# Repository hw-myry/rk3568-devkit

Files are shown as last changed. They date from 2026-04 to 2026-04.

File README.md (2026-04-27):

# rk3568-devkit

## Overview

**SoC**: RK3568  
**RAM**: LPDDR4  
**Storage**: eMMC  

**Interfaces**:  
USB OTG / USB2.0 / USB3.0 / PCIe 2.0  
MIPI DSI / MIPI CSI / HDMI  

**Ethernet**:  
RTL8211F-CG (Gigabit)

**Power**:  
RK809-5 PMIC  
CH224K (12V PD trigger)

**Debug**:  
UART  

**Audio**:  
MIC / SPK / Headphone

<p align="center">
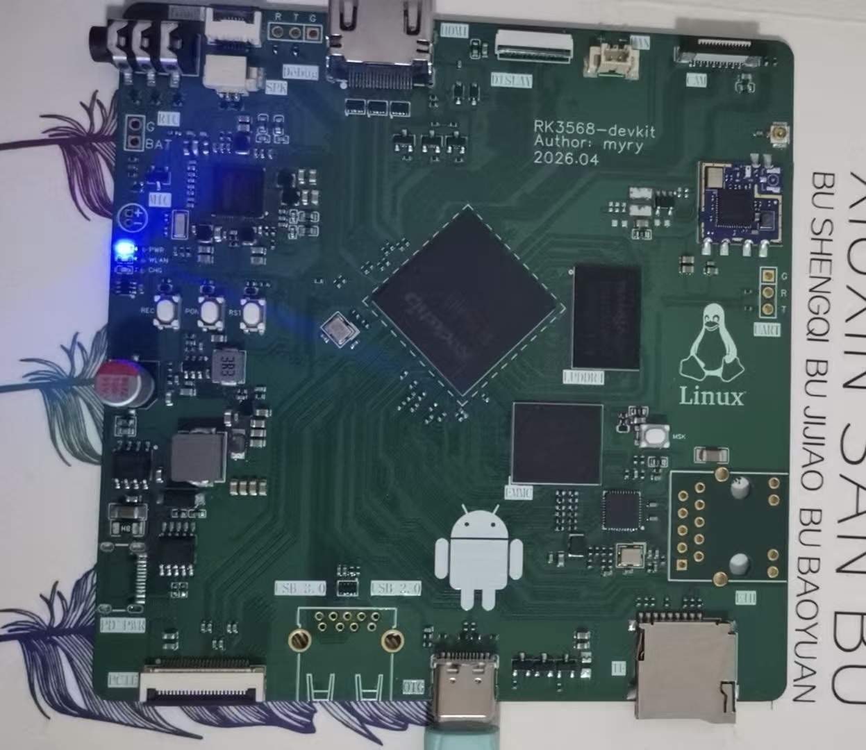
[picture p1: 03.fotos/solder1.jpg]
  
</p>

<p align="center">
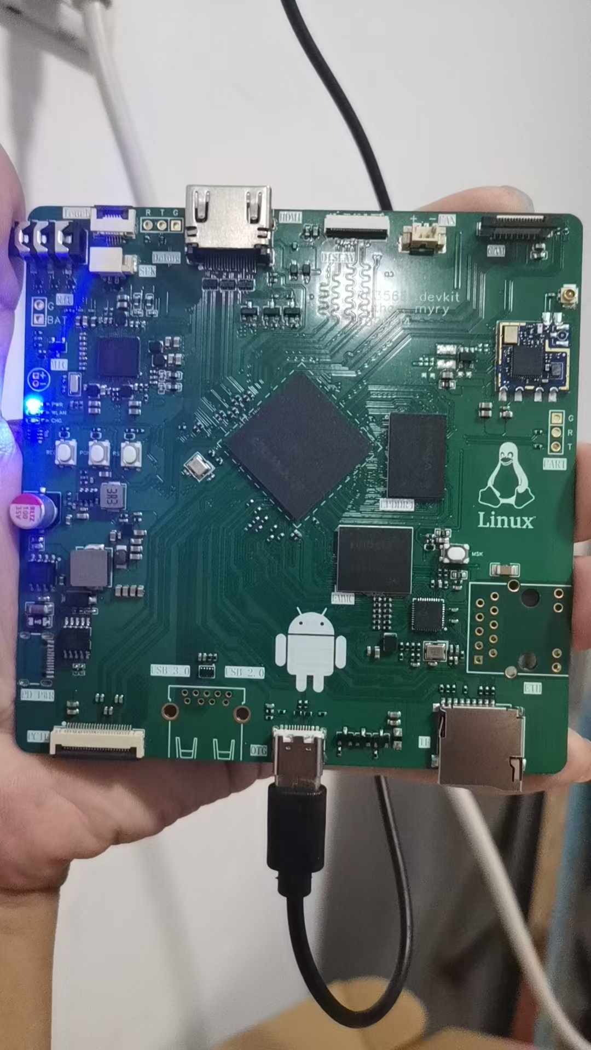
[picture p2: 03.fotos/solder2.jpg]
  
</p>

<p align="center">
  
</p>

<p align="center">
  
</p>

<p align="center">
  
</p>

<p align="center">
  
</p>

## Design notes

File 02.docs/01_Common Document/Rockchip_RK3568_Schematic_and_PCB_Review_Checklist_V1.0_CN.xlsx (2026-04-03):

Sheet: 封面页
RK3568原理图及PCB评审注意事项
Revision: | V1.0
Date: | 2021-04-16
Status: | Draft
Rockchip Confidential

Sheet: 声明
保密提示： 本文档及其附件可能含有机密信息，来自瑞芯微电子股份有限公司，仅发送给指定接收者。若非该特定接收人，请勿复制、 使用或披露本文档的任何内容。若误收本文档，请从系统中永久性删除本文档，并以回复邮件或其他方式即刻告知发件人。瑞芯微电子股份有限公司拥有本文档信息的著作权及解释权，禁止任何未经授权许可的侵权行为。 IMPORTANT NOTICE: This document is from Rockchip Electronics Co., Ltd. .The contents of this document and any attachments may contain information that is privileged, confidential and/or exempt from disclosure under applicable law and relevant NDA. If you are not the intended recipient, you are hereby notified that any disclosure, copying, distribution, or use of the information is STRICTLY PROHIBITED. Please immediately contact the sender as soon as possible and destroy the material in its entirety in any format. Thank you.

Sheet: 历史版本
Revision History
Revision | Description | Editor | Revision Date
V1.0 | First edition | Zhangdz | 2021.04.16

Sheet: Clock&Reset&PMU Circuit
类型 |  | 项目 | 要求 | 风险点及影响 | 是否验证? | 审核人 | 备注
平台共性 | 原理图 | 晶体负载电容请根据实际使用的晶体的CL电容值选择，并控制常温下的频率容限在20ppm以内，负载电容材质建议采用COG或NPO | 必须 | 设计要求
 |  | XOUT24M网络串接电阻（22ohm）必须保留，用于限流，防止过驱 | 必须 | 设计要求
 |  | XOUT24M和XIN24M网络之间的1M电阻不能随意修改 | 必须 | 设计要求
 |  | 建议采用贴片4Pin晶体，其中2个GND管脚与PCB板的地充分连接，加强时钟抗ESD干扰能力 | 必须 | 设计要求
 |  | TVSS管脚必须直接接地 | 必须 | 设计要求
 |  | 芯片nPOR管脚（RESETn网络）为输入管脚，必须由外部控制，默认由RK809-5控制，如果采用其它方案外部必须增加复位IC | 必须 | 设计要求
 |  | TSADC_SHUT包含了过温复位输出以及看门狗复位输出，由于TSADC_SHUT会连接到Resetn网络上，如果采用复位IC，必须使用OD输出，有效信号为低电平，复位时间不小于10mS即可 | 必须 | 设计要求
 |  | 芯片nPOR管脚（RESETn网络）需放置100nF电容，加强抗ESD干扰能力 | 必须 | 设计要求
 |  | PMIC_SLEEP和TSADC_SHUT是特定功能信号，不得随意更改。 | 必须 | 设计要求
 |  | FLASH_VOL_SEL管脚必须根据实际VCCIO2供电电压选择正确的高低电平（上拉或下拉），决定VCCIO2电源域供电电压和驱动电压是否匹配。 | 必须 | 设计要求
 |  | REFCLK_OUT网络建议串接22 ohm电阻，并靠近RK3568放置，提高信号质量。 | 必须 | 设计要求
 |  | 如果深度睡眠功耗要求比较极致，睡眠时钟需要外部提供，从Pin AD23管脚（CLK32K_IN）输入32.768KHz时钟。 | 可选项 | 影响二级待机功耗
 |  | 要求PMUPLL_AVDD_0V9，PMUPLL_AVDD_1V8，SYSPLL_AVDD_0V9，SYSPLL_AVDD_1V8，PMUIO1，PMUIO2，PMU_VDD_LOGIC_0V9电源的去耦电容不能删除，要求复制参考图设计 | 必须 | 设计要求
 | PCB | 晶体电路布局需要优先考虑，布局时应与芯片在同一层并尽量靠近放置以避免打过孔，晶体走线尽可能的短，远离干扰源，尽量远离板边缘， | 必须 | 设计要求
 |  | 晶体以及时钟信号需要全程包地处理，包地线每隔200mil至少添加一个GND过孔，并且必须保证邻层的地参考面完整。 | 必须 | 设计要求
 |  | 晶体电路布局时如果与芯片不同层放置，晶体走线及必须全程包地处理，避免被干扰。 | 必须 | 设计要求
 |  | PMUPLL_AVDD_0V9，PMUPLL_AVDD_1V8，SYSPLL_AVDD_0V9，SYSPLL_AVDD_1V8，PMUIO1，PMUIO2，PMU_VDD_LOGIC_0V9电源的去耦电容，必须放在芯片管脚背面，走线时，尽量形成先经过电容焊盘再到芯片管脚。 | 必须 | 设计要求
 |  | 在布局时，RESETn复位信号远离板边缘和金属接插件，以防止因ESD引起的异常而导致复位模块死机。 | 必须 | 设计要求
 |  | RESETn的滤波电容应尽量靠近芯片管脚布局，信号需先经过电容，再进入芯片，注意滤波电容的地焊盘必须有一个0402地过孔，空间允许建议打两个以上，更良好的接地。 | 必须 | 设计要求
 |  | RESETn信号应远离DCDC、RF等强干扰信号，以防止受到干扰。如果走线较长，建议包地处理，并且包地线每隔400mil至少添加一个GND过孔。 | 必须 | 设计要求
 |  | REFCLK_OUT必须全程包地处理，包地的走线间隔300mil以内必须有地过孔 | 必须 | 设计要求
 |  | RESETn按键的TVS保护二级管应尽量靠近按键放置，信号拓扑为：按键--->TVS--->100 ohm--->电容（靠近CPU&PMIC）--->CPU&PMIC；出现ESD现象时，ESD电流必须先经过TVS器件衰减。 | 必须 | 设计要求
扩展需求 | 原理图
 | PCB

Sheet: Debug UART&JTAG
类型 |  | 项目 | 要求 | 风险点及影响 | 是否验证? | 审核人 | 备注
平台共性 | 原理图 | UART2_RX_M0/UART2_TX_M0串接的100 ohm电阻不得删减，建议增加TVS管，加强抗静电浪涌能力，防止开发过程损坏芯片管脚。 | 必须 | 设计要求
 |  | 能预留2.54 插针建议尽量预留，如果无条件，建议使用0.7mm以上测试点，方便焊接。 | 必须 | 设计要求
 |  | RK3568的A55 Core JTAG Debug 只支持SWD模式，只需要预留ARMJTAG_TCK/ARMJTAG_TMS，和SDMMC0_D2/SDMMC0_D3复用，默认由SDMMC0_DET管脚（Pin Y22）做硬件切换，要进入JTAG模式，必须保证SDMMC0_DET管脚处于高电平，否则无法进入JTAG调试模式 | 必须 | 设计要求
 | PCB | TVS保护二级管应尽量靠近座子放置，信号拓扑为：接口--->TVS--->CPU；出现ESD现象时，ESD电流必须先经过TVS器件衰减；TVS器件走线上不要有残桩(Stub) | 必须 | 设计要求
 |  | TVS的地管脚建议尽量增加地过孔，至少保证2个0.4*0.2mm的过孔，加强静电泄放能力 | 必须 | 设计要求
扩展需求 | 原理图
 | PCB

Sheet: PMIC&Power
类型 |  | 项目 | 要求 | 风险点及影响 | 是否验证? | 审核人 | 备注
平台共性 | 原理图 | 默认电源方案采用RK809-5，即参考设计所提供的参考电路，如果需要更换，LDO/BUCK的带载能力、瞬态响应以及功率耗散要满足设计要求。如果不知道每一路电源的功耗数据，可向Rockchip申请EVB的电源测试数据做参考。 对BUCK的主要要求如下： 1）输出电压精度要求在±1.5% 2）BUCK瞬态响应要求：Iload=BUCK Max电流*10%-BUCK Max电流*80% 跳变，斜率1A/us，纹波要求±3%以内。 3）带载能力建议大于实际场景的最大峰值电流的150% 如果对整机功耗敏感的，还需要考虑一下效率问题。 | 必须 | 设计要求
 |  | RK3568芯片的每路电源管脚的去耦电容不得删减，要求参照参考设计。 | 必须 | 设计要求
 |  | 针对RK809-5电源方案的上下电时序：不能更改，已固化。 针对分立电源方案 上电时序：理论上遵循低压先上、高压后上，待最后一个电压上电稳定后，RESETn至少保证10mS才能释放，各模块上电时序要求请见《Rockchip_RK3568_Hardware_Design_Guide》 下电时序：VCC3V3_PMUIO电压降低于2.93V时 ，RESETn必须先拉低动作，其它电源随着下电。 | 可选项 | 设计要求
 |  | 如果有需要钮扣电池保存实时时钟，建议使用外部RTC IC（RK809-5的RTC电流大概35~50uA）。 | 可选项 | 设计要求
 |  | 使用外部的RTC IC当实时时钟，如果需要定时闹钟开机功能，请联系Rockchip FAE提供参考电路。 RK809-5自带的RTC支持定时闹钟开机功能。 使用外部的RTC IC必须确认一下其IO的电平和RTC芯片供电电源电压是否匹配 | 可选项 | 设计要求
 |  | RK809-5的32.768KHz晶体负载电容请根据实际使用的晶体的CL电容值选择，建议选择不低于18pF，负载电容过低有可能会造成起振不稳定，推荐值为22pF | 必须 | 设计要求
 |  | 适配器需要根据产品规格进行选型，比如有多个SATA或多个PCIe插槽需求，适配器输出的带载能力必须匹配上，RK3568以及最小系统这边需要按6-10W空间预留 | 必须 | 设计要求
 |  | 12V适配器方案： VCC5V0_SYS要求选择≥3A供电能力的BUCK。 VCC3V3_SYS要求选择≥3A供电能力的BUCK。 VCC5V0_USB要求选择≥3A供电能力的BUCK，如果有更多的USB接口或SATA接口的需求，供电能力必须匹配上。 | 必须 | 设计要求
 |  | DC输入端建议放置RC电路，可吸收DC插入瞬间的峰值电压，注意电阻的功率和电容的耐压。 | 必须 | 设计要求
 |  | DC输入端建议放置100uF以上容量的电容，改善电源纹波。
 |  | VCC5V0_SYS,VCC3V3_SYS,VCC5V0_USB建议各放置100uF以上容量的电容，获取最好的电源纹波。 | 必须 | 设计要求
 |  | 如果有需求快速上下电测试的产品，要注意电解电容的放电时间，如果存在下电不彻底又重新上电了，可能会引起系统工作异常，这种情况就需要考虑对其加放电电路处理，请联系Rockchip提供参考方案电路。 | 必须 | 设计要求
 |  | PMIC RK809-5电源时序以及电源分配是固定的，不能随意改动各路电源分配好的LDO和DC-DC。 | 必须 | 设计要求
 |  | PMIC RK809-5的DC-DC电感参考值为：感量0.47uH，饱和电流3.5A以上，DCR小于50毫欧。 | 必须 | 设计要求
 |  | PMIC RK809-5的DC-DC、LDO的输入输出电容容量需要参照参考设计，不能随意修改。 | 必须 | 设计要求
 |  | PMIC RK809-5的BUCK3输出电压值是由外围电阻决定的，必须根据项目所用的DDR类型匹配电压值，参考电压为0.8V，选择分压电阻RH=(VBUCK3-0.8)*RL/0.8，RH和RL分别为分压上拉电阻和下拉电阻，阻值选择建议在10KΩ 到1MΩ 之间，精度为1%，建议参照参考设计提供的参数。 | 必须 | 设计要求
 |  | USB_AVDD_0V9，USB_AVDD_1V8，MIPI_AVDD_0V9，MIPI_AVDD_1V8这几路电源必须串磁珠进行隔离，磁珠规格为120R-100MHz | 必须 | 设计要求
 |  | PMIC RK809-5外围器件必须完整复制参考设计，不得随意删减。 | 必须 | 设计要求
 |  | PMIC RK809-5的Pin 67（RESETB）也需要有100nF电容，加强抗ESD干扰能力，不能随意删掉。 | 必须 | 设计要求
 |  | PMIC RK809-5的SDA\SCL\INT \CLK32K\RESETB 这几个GPIO 是开漏输出的，允许输入的最高电压是VCC_RTC的电压，外部需要额外增加上拉电阻或使用RK3568 IO内部的上拉电阻。 SCL\SDA\SLEEP\PWRON\RESETB 做为输入VL\VH 是固定的0.4V\1.26V | 必须 | 设计要求
 |  | PMIC RK809-5的VCC_RTC（Pin45）：是RK809 芯片内部数字逻辑、部份模拟控制及RTC 时钟供电引脚 ，该脚设计时要求供电电压必须是RK809 所有供电脚中的最高电压（或是大于Vmax-0.3V），所以VCC_RTC 必须最先上电，或和其它电源一起上电，不允许出现VCC_RTC没电而其它电源先供电的情况。 建议和RK809-5的VCC9（Pin54）接同一个电源 | 必须 | 设计要求
 |  | RK809-5 VDC(Pin61）输入电压值推荐值为1.2V左右，不建议随意修改 | 必须 | 设计要求
 |  | 如果Gas Gauge不使用，建议Pin56（BATDIV）,Pin62（SNSP）,Pin63（SNSN）接地处理 | 必须 | 设计要求
 |  | 如果项目不使用RK809-5 CODEC功能，那么RK809-5的 Pin14(LRCLK),Pin15(BCLK),Pin16(MCLK),Pin17(SDI),Pin19(PDMCLK),Pin40(HP_SNS) 需要接地VSS处理， Pin18(SDO/PDMDATA),Pin36(CPn),Pin37(CPp),Pin38(VCC_CPVDD),Pin35(VCC_CPVSS),Pin39(HPL_OUT),Pin41(HPR_OUT),Pin34(SPK_OUTn),Pin32(SPK_OUTp),Pin43(MIC1p),Pin42(MIC1n)悬空处理即可 Pin33(VCC_SPK_HP),Pin48(VCC_1P8D),Pin44(VCC_1P8A)的电路必须保留。 | 必须 | 设计要求
 |  | VDD_LOGIC,VDD_GPU,VDD_NPU,VDD_CPU这几路电源DC-DC采用远端引入反馈补偿设计，弥补线路的电压损耗及提高电源动态调整及时性，由于实际生产或使用过程中若出现远端的反馈节点开路的情况，所以要求在DC-DC侧增加100 ohm电阻，这个电阻可以使输出电压依然稳定在设定值，避免因反馈点开路导致DC-DC输出电压失控导致主控过压损坏，另外反馈补偿线与电源线存在一个环路，某些设计可能会感应到噪声影响DC-DC，这个电阻可以在一定程度上减小这个影响，为了提升瞬态响应，在100 ohm电阻上面再并了一个100nF电容。 100ohm电阻和100nF电容不能随意删减。 | 必须 | 设计要求
 |  | VDD_CPU采用动态电压频率调整，要求参照参考图设计，通过I2C进行调压，如需更换其它型号，要求选择≥4A供电能力的BUCK BUCK其它要求如下： 1）输出电压精度要求在±1.5% 2）BUCK瞬态响应要求：Iload=BUCK Max电流*10%-BUCK Max电流*80% 跳变，斜率1A/us，纹波要求±5%以内。 | 必须 | 设计要求
 |  | 请勿删除参考图中电源管脚串接的电阻或磁珠，因为芯片需要RC或LC滤波设计 | 必须 | 设计要求
 | PCB | 整体布局时从电源质量角度上看RK809-5尽量靠近RK3568（考虑散热设计时，需要适当放置，不要太靠近也不能离的太远，建议间隔20mm-50mm之间，尽量不放置在板边，对散热不利），摆放方向时，需要使RK809-5的BUCK输出到RK3568的走线（铺铜）是顺的，不要存在交叉。 | 必须 | 设计要求
 |  | RK809-5的BUCK1/BUCK2 PCB设计要求： 输入电容必须离芯片尽可能近，输入电容与VCC1/2 和GND 的连接环路尽可能小。应当保证SW1/2 的走线尽可能短，防止对其他模块造成干扰；VFB1/2 走线应当尽量避免离SW1/2 太近。 对于需要打过孔的地方，VCC1/2 至少需要4个0.5*0.3mm 的过孔，VBUCK1/2 至少需要5 个0.5*0.3mm的过孔。 特别注意输入输出电容的GND 端要有和正端一样多数量的过孔，才能起到比较好的虑波效果。 | 必须 | 设计要求
 |  | RK809-5的BUCK3 PCB设计要求： 输入电容必须离芯片尽可能近，输入电容与VCC3 和GND 的连接环路尽可能小。应当保证SW3 的走线尽可能短，防止对其他模块造成干扰；VFB3 走线应当尽量避免离SW3 太近。 对于需要打过孔的地方，VCC3至少需要3 个0.5*0.3mm的过孔，VBUCK3 至少需要5 个0.5*0.3mm的过孔。 特别注意输入输出电容的GND 端要有和正端一样多数量的过孔，才能起到比较好的虑波效果。 | 必须 | 设计要求
 |  | RK809-5的BUCK4 PCB设计要求： 输入电容必须离芯片尽可能近，输入电容与VCC4 和GND 的连接环路尽可能小。应当保证SW4 的走线尽可能短，防止对其他模块造成干扰；VFB4 走线应当尽量避免离SW4太近。 对于需要打过孔的地方，VCC4至少需要3 个0.5*0.3mm的过孔，VBUCK4 至少需要5 个0.5*0.3mm的过孔。 特别注意输入输出电容的GND 端要有和正端一样多数量的过孔，才能起到比较好的虑波效果。 | 必须 | 设计要求
 |  | RK809-5的BUCK5 PCB设计要求： 输入电容必须离芯片尽可能近，输入电容与VCC9 和GND 的连接环路尽可能小。应当保证SW5 的走线尽可能短，防止对其他模块造成干扰；VFB5 走线应当尽量避免离SW5太近。 对于需要打过孔的地方，VCC9至少需要3 个0.5*0.3mm的过孔，VBUCK5 至少需要5 个0.5*0.3mm的过孔。 特别注意输入输出电容的GND 端要有和正端一样多数量的过孔，才能起到比较好的虑波效果。 | 必须 | 设计要求
 |  | RK809-5的LDO PCB设计要求： 输入电容必须离芯片尽可能近，输入电容与VCC5/6/7/8和GND 的连接环路尽可能小。 输出电容必须离芯片尽可能近，输出电容与LDO1/2/3/4/5/6/7/8/9和GND 的连接环路尽可能小。 | 必须 | 设计要求
 |  | RK809-5的32.768KHz晶体的XIN/XOUT信号走线越短越好且全程做包地处理，保证有完整的参考平面，晶体电路下不能有高速信号穿过。 | 必须 | 设计要求
 |  | RK809-5的VREF电容必须靠近管脚放置，远离其它干扰源，电容的地焊盘必须良好接地，即VREF电容地焊盘和RK809-5 EPAD之间路径必须保证最短，不得被其他信号分割。 | 必须 | 设计要求
 |  | RK809-5的Pin 67（RESETB）的100nF电容必须靠近RK809-5管脚
 |  | 建议RK809-5的管脚禁铺铜，所有管脚通过走线方式和外面连接，走线线宽不得超过管脚宽度，防止制板后，焊盘变大后贴片容易连锡 | 必须 | 设计要求
 |  | RK809-5的EPAD接地焊盘要有足够的过孔，建议保证5*5个0.5*0.3mm或是6*6个0.4*0.2mm的过孔以上，降低接地阻抗，以及加强热量传导。 | 必须 | 设计要求
 |  | VDD_CPU（TCS4525）BUCK的PCB设计要求： 整体布局时，尽量靠RK3568。 输入电容必须离芯片尽可能近，输入电容与VIN和GND 的连接环路尽可能小。应当保证SW 的走线尽可能短，防止对其他模块造成干扰；VOUT 走线应当尽量避免离SW 太近。输出电容和GND的连接环路尽可能有小。 对于需要打过孔的地方，VIN至少需要5 个0.5*0.3mm的过孔，Vbuck输出至少需要12 个0.5*0.3mm的过孔。 特别注意输入输出电容的GND 端要有和正端一样多数量的过孔，才能起到比较好的虑波效果。 | 必须 | 设计要求
 |  | VDD_LOGIC,VDD_GPU,VDD_NPU,VDD_CPU的DC-DC 100ohm反馈电阻需要靠近输出电容放置，电阻一端连接到DC-DC输出电容，另一端连接到PMIC的FB反馈脚上，并同时连接到CPU同一电源网络的最远端负载处。反馈线宽度使用4mil，必须与电源铺铜伴随走线，以避免干扰；反馈线与其他信号间隔6mil以上，比如VDD_GPU的反馈线图片 | 必须 | 设计要求
 |  | VDD_LOGIC,VDD_GPU,VDD_NPU,VDD_CPU,VCC_DDR的铺铜宽度需满足芯片的电流需求，连接到芯片电源管脚的铺铜足够宽，路径不能被过孔分割太严重，必须计算有效线宽，确认连接到CPU每个电源PIN脚的路径都足够。 VDD_LOGIC：CPU区域的线宽不得小于60mil，外围区域宽度不小于200mil，尽量采用铺铜方式，降低走线带来压降 VDD_GPU：CPU区域的线宽不得小于50mil，外围区域宽度不小于200mil，尽量采用铺铜方式，降低走线带来压降 VDD_NPU：CPU区域的线宽不得小于50mil，外围区域宽度不小于200mil，尽量采用铺铜方式，降低走线带来压降 VDD_CPU：CPU区域的线宽不得小于120mil，外围区域宽度不小于200mil，尽量采用铺铜方式，降低走线带来压降 VCC_DDR：CPU区域的线宽不得小于120mil，外围区域宽度不小于200mil，尽量采用铺铜方式，铺铜覆盖DDR走线区域，降低走线带来压降 | 必须 | 设计要求
 |  | 芯片的各路电源在外围换层时，要尽可能的多打电源过孔，降低换层过孔带来的压降；去耦电容的GND过孔要跟它的电源过孔数量保持一致，否则会大大降低电容作用。 VDD_LOGIC:8个以上0.5*0.3mm的过孔 VDD_GPU:5个以上0.5*0.3mm的过孔 VDD_NPU:5个以上0.5*0.3mm的过孔 VDD_CPU:12个以上0.5*0.3mm的过孔 VCC_DDR:8个以上0.5*0.3mm的过孔 芯片其它电源：1个以上0.5*0.3mm的过孔或2个以上0.4*0.2mm的过孔 芯片外围电源：根据实际电流放置。 | 必须 | 设计要求
 |  | RK3568芯片的相邻层必须是一个完整的GND平面，保证主参考地靠近CPU的Ball，用于保证电源完整性以及加强PCB的散热。 | 必须 | 设计要求
 |  | RK3568芯片的Power管脚，每个Ball需要对应一个过孔。 | 必须 | 设计要求
 |  | RK3568芯片的GND管脚，至少保证每1.5个ball需要对应一个过孔，尽量每个Ball对应一个过孔，提供更优的SI,PI条件，以及对散热也有帮助。 | 必须 | 设计要求
 |  | RK3568芯片下方相同网络的Power Ball和GND Ball在顶层走“井”字形，交叉连接，建议走线线宽10mil | 必须 | 设计要求
 |  | GND层设计：在Layout时，RK3568的各信号放置换层过孔时，要求打在Ball间隔的正中间，要有规律的放置，如图，GND层的铺铜情况，RK3568芯片中间的地有大面积的铜皮和外面地铜皮连接，一方面有利于电源，信号完整性，另外一方面有利于芯片散热。 | 必须 | 设计要求
 |  | RK3568的各路电源去耦电容务必放在对应的电源管脚背面，特别是VDD_LOGIC,VDD_GPU,VDD_NPU,VDD_CPU,VCC_DDR电源至少放一个10uF以上容量的电容在管脚背面，电容的GND pad靠近芯片中心的GND Ball放置。 | 必须 | 设计要求
 |  | 去耦电容的换层过孔要满足带载能力，不管是电源输入、电源输出还是接地，必须有足够多的过孔，才能保证低ESR（用于减低回路电感），保证电容的去耦效果。 Rockchip建议10uF容量以上去耦电容，一个焊盘提供两个以上0.4*0.2mm的过孔，10uF以下容量的电容，一个焊盘提供至少一个0.4*0.2mm的过孔，过孔要靠近电容焊盘。 | 必须 | 设计要求
 |  | 电源部分布局远离其它发热源，以控制局部发热量过高不利于散热的问题。
 |  | 电源部分布局时应远离板边及金属接插件，防止ESD干扰。 | 必须 | 设计要求
扩展需求 | 原理图 Schematic | 如果使用RK809-5的电量计，请联系Rockchip申请参考电路图。 | 可选项
 | PCB | PMIC的32.768K晶体，如果使用金属圆柱体封装，金属外壳应接地。 | 必须 | 保证时钟稳定
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

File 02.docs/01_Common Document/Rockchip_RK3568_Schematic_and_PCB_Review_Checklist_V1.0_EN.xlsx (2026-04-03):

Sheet: title page
RK3568 Schematic and PCB Review Checklist
Revision: | V1.0
Date: | 2022-01-25
Status: | Draft
Rockchip Confidential

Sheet: state
保密提示： 本文档及其附件可能含有机密信息，来自瑞芯微电子股份有限公司，仅发送给指定接收者。若非该特定接收人，请勿复制、 使用或披露本文档的任何内容。若误收本文档，请从系统中永久性删除本文档，并以回复邮件或其他方式即刻告知发件人。瑞芯微电子股份有限公司拥有本文档信息的著作权及解释权，禁止任何未经授权许可的侵权行为。 IMPORTANT NOTICE: This document is from Rockchip Electronics Co., Ltd. .The contents of this document and any attachments may contain information that is privileged, confidential and/or exempt from disclosure under applicable law and relevant NDA. If you are not the intended recipient, you are hereby notified that any disclosure, copying, distribution, or use of the information is STRICTLY PROHIBITED. Please immediately contact the sender as soon as possible and destroy the material in its entirety in any format. Thank you.

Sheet: revision history
Revision History
Revision | Description | Editor | Revision Date
V1.0 | First edition | Zhangdz | 2021.04.16

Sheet: Clock&Reset&PMU Circuit
Type |  | Item | Requirement | Risk & Influence | Is it verified? | Reviewer | Remark
Platform Commonality | Schematic | Please select the crystal load capacitor according to the CL capacitance value of the crystal actually used, and control the frequency tolerance at room temperature within 20ppm. The material of the load capacitor is recommended to use COG or NPO. | Mandatory | Design requirement
 |  | XOUT24M network series resistor (22ohm) must be reserved for current limiting and preventing overdrive | Mandatory | Design requirement
 |  | The 1M resistance between the XOUT24M and XIN24M networks cannot be modified at will | Mandatory | Design requirement
 |  | It is recommended to use SMD 4Pin crystal, of which 2 GND pins are fully connected to the ground of the PCB board to enhance the anti-ESD interference capability of the clock | Mandatory | Design requirement
 |  | TVSS pin pin must be directly grounded | Mandatory | Design requirement
 |  | The nPOR pin (RESETn network) of the chip is an input pin, which must be controlled externally. It is controlled by RK809-5 by default. If other solutions are used, an external reset IC must be added. | Mandatory | Design requirement
 |  | TSADC_SHUT includes over temperature reset output and watchdog reset output. Since TSADC_SHUT will be connected to the Resetn network, if a reset IC is used, OD output must be used, the valid signal is low level, and the reset time is not less than 10mS. | Mandatory | Design requirement
 |  | The chip nPOR pin (RESETn network) needs to place a 100nF capacitor to enhance the anti-ESD interference ability | Mandatory | Design requirement
 |  | PMIC_SLEEP and TSADC_SHUT are function specific signals and should not be changed arbitrarily. | Mandatory | Design requirement
 |  | The FLASH_VOL_SEL pin must select the correct high and low level (pull-up or pull-down) according to the actual VCCIO2 power supply voltage to determine whether the power supply voltage of the VCCIO2 power domain matches the driving voltage. | Mandatory | Design requirement
 |  | It is recommended to connect a 22 ohm resistor in series with the REFCLK_OUT network and place it close to the RK3568 to improve signal quality. | Mandatory | Design requirement
 |  | If the power consumption of deep sleep is extreme, the sleep clock needs to be provided externally, and the 32.768KHz clock is input from the Pin AD23 pin (CLK32K_IN). | Optional | Affects secondary standby power consumption
 |  | It is required that the decoupling capacitors of the PMUPLL_AVDD_0V9, PMUPLL_AVDD_1V8, SYSPLL_AVDD_0V9, SYSPLL_AVDD_1V8, PMUIO1, PMUIO2, PMU_VDD_LOGIC_0V9 power supplies cannot be deleted, and the reference diagram design is required to be copied | Mandatory | Design requirement
 | PCB | The crystal circuit layout needs to be prioritized. The layout should be placed on the same layer as the chip and placed as close as possible to avoid vias. The crystal traces should be as short as possible, away from interference sources, and as far away as possible from the edge of the board. | Mandatory | Design requirement
 |  | The crystal and clock signals need to be grounded in the whole process. At least one GND via is added every 200mil to the grounded wire, and the ground reference plane of the adjacent layer must be guaranteed to be complete. | Mandatory | Design requirement
 |  | If the crystal circuit layout is placed on a different layer from the chip, the crystal wiring and wiring must be handled in the whole process to avoid interference. | Mandatory | Design requirement
 |  | PMUPLL_AVDD_0V9, PMUPLL_AVDD_1V8, SYSPLL_AVDD_0V9, SYSPLL_AVDD_1V8, PMUIO1, PMUIO2, PMU_VDD_LOGIC_0V9 power supply decoupling capacitors must be placed on the back of the chip pins. When routing, try to form them first through the capacitor pads and then to the chip pins. | Mandatory | Design requirement
 |  | During layout, the RESETn reset signal is kept away from the board edge and metal connectors to prevent the reset module from crashing due to anomalies caused by ESD. | Mandatory | Design requirement
 |  | The filter capacitor of RESETn should be placed as close as possible to the chip pins. The signal needs to pass through the capacitor first, and then enter the chip. Note that the ground pad of the filter capacitor must have a 0402 ground via. It is recommended to use more than two if the space allows, for better grounding. | Mandatory | Design requirement
 |  | The RESETn signal should be kept away from strong interference signals such as DCDC and RF to prevent interference. If the trace is long, it is recommended to cover the ground, and add at least one GND via hole every 400mil. | Mandatory | Design requirement
 |  | REFCLK_OUT must be grounded in the whole process, and the grounded traces must have ground vias within 300mil | Mandatory | Design requirement
 |  | The TVS protection diode of the RESETn button should be placed as close as possible to the button. The signal topology is: button--->TVS--->100 ohm--->capacitor (close to CPU&PMIC)--->CPU&PMIC; when ESD occurs, The ESD current must first decay through the TVS device. | Mandatory | Design requirement
Extended Requirement | Schematic
 | PCB

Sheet: Debug UART&JTAG
Type |  | Item | Requirement | Risk & Influence | Is it verified? | Reviewer | Remark
Platform Commonality | Schematic | The 100 ohm resistor connected in series with UART2_RX_M0/UART2_TX_M0 must not be deleted. It is recommended to add a TVS tube to enhance the anti-static surge capability and prevent the chip pins from being damaged during the development process. | Mandatory | Design requirement
 |  | It is recommended to reserve 2.54 pins as much as possible. If there are no conditions, it is recommended to use a test point of 0.7mm or more, which is convenient for welding. | Mandatory | Design requirement
 |  | A55 Core JTAG Debug of RK3568 only supports SWD mode, only need to reserve ARMJTAG_TCK/ARMJTAG_TMS, multiplex with SDMMC0_D2/SDMMC0_D3, the default is SDMMC0_DET pin (Pin Y22) for hardware switching, to enter JTAG mode, it must be ensured that SDMMC0_DET pin is in High level, otherwise cannot enter JTAG debug mode | Mandatory | Design requirement
 | PCB | The TVS protection diode should be placed as close as possible to the socket, and the signal topology is: interface--->TVS--->CPU; when ESD occurs, the ESD current must be attenuated by the TVS device first; there should be no residue on the TVS device trace. Stub | Mandatory | Design requirement
 |  | It is recommended to increase the ground vias as much as possible for the ground pins of TVS, and at least ensure 2 vias of 0.4*0.2mm to enhance the electrostatic discharge capability. | Mandatory | Design requirement
Extended Requirement | Schematic
 | PCB
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

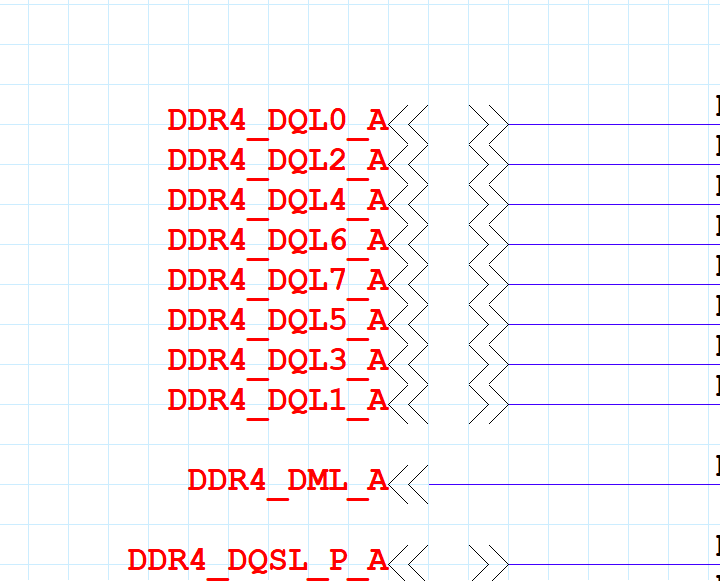
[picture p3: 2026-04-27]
02.docs/04_Product Line Branch(NVR)/03_Demo Reference Design/SCH/RK_NVR_DEMO_RK3568_DDR4P216SD4_V12_20201221.png

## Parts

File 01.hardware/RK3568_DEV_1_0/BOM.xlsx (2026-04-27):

No. | Quantity | Comment | Designator | Footprint | Value
1 | 1 | 0.1uF | C1 | C0201 | 0.1uF
2 | 14 | 22uF | C2,C3,C7,C8,C9,C13,C14,C15,C17,C18,C212,C214,C342,C343 | C0603 | 22uF
3 | 7 | 100nF | C4,C5,C138,C510,C538,C540,C543 | C0603 | 100nF
4 | 38 | 100nF | C6,C11,C16,C21,C23,C25,C27,C29,C30,C32,C33,C35,C36,C37,C38, C39,C40,C41,C42,C43,C44,C46,C48,C49,C52,C53,C56,C57,C58,C60, C63,C64,C66,C68,C69,C70,C71,C72 | C0201 | 100nF
5 | 8 | 4.7uF | C10,C12,C222,C223,C227,C228,C229,C244 | C0402 | 4.7uF
6 | 4 | 100nF | C19,C221,C225,C226 | C0201 | 100nF
7 | 2 | 22pF | C20,C22 | c0402-nsk | 22pF
8 | 9 | 1uF | C24,C26,C31,C34,C108,C132,C238,C541,C542 | c0402-nsk | 1uF
9 | 1 | 1uF | C28 | C0402 | 1uF
10 | 8 | 4.7uF | C45,C47,C50,C51,C185,C187,C190,C192 | c0402-nsk | 4.7uF
11 | 2 | 100pF | C54,C201 | c0402-nsk | 100pF
12 | 17 | 22uF | C55,C59,C62,C75,C84,C85,C98,C101,C103,C146,C166,C207,C215,C216,C217,C218,C339 | C0603_1 | 22uF
13 | 1 | 1uF | C61 | C0201 | 1uF
14 | 2 | 10uF | C65,C67 | C0603_1 | 10uF
15 | 26 | 1uF | C73,C74,C77,C78,C79,C80,C81,C86,C87,C88,C89,C90,C92,C93,C95,C96,C97,C105,C106,C107, C113,C114,C117,C118,C149,C197 | R0402_1 | 1uF
16 | 13 | 10uF | C76,C82,C83,C91,C94,C99,C102,C104,C139,C147,C148,C240,C341 | C0603_2 | 10uF
17 | 47 | 100nF | C100,C123,C126,C127,C128,C129,C140,C141,C142,C143,C144,C145,C150,C151,C152,C153,C154,C155,C156, C157,C158,C159,C160,C161,C162,C163,C164,C165,C169,C170,C171,C172,C173,C174,C175,C176,C177,C178, C179,C180,C181,C182,C183,C195,C196,C336,C337 | R0402_1 | 100nF
18 | 1 | 4.7uF | C109 | R0402_1 | 4.7uF
19 | 29 | 100nF | C110,C131,C135,C136,C137,C184,C186,C189,C191,C193,C194,C202,C208,C209,C210,C347,C352,C353,C354, C355,C356,C359,C360,C361,C363,C364,C498,C515,C528 | c0402-nsk | 100nF
20 | 4 | 100nF | C111,C115,C119,C122 | R0402_3 | 100nF
21 | 2 | 12pF | C112,C116 | R0402_2 | 12pF
22 | 2 | 680pF | C120,C121 | R0402_1 | 680pF
23 | 2 | 27pF | C124,C125 | R0402_1 | 27pF
24 | 2 | 22uF | C130,C134 | c0603-nsk | 22uF
25 | 1 | 100nF | C133 | R0603 | 100nF
26 | 2 | 10uF | C167,C168 | R0402_1 | 10uF
27 | 1 | 2.2uF | C188 | c0402-nsk | 2.2uF
28 | 1 | 220pF | C198 | R0402_1 | 220pF
29 | 1 | 1uF | C199 | C0402_1 | 1uF
30 | 1 | DNP | C200 | c0402-nsk | 1nF
31 | 3 | 10uF | C211,C224,C514 | C0603 | 10uF
32 | 1 | 10uF | C213 | R0603 | 10uF
33 | 2 | 1uF | C219,C220 | MYC0402 | 1uF
34 | 2 | 4.7uF | C234,C351 | C0603 | 4.7uF
35 | 1 | 100nF | C239 | R0603_1 | 100nF
36 | 1 | 22pF | C338 | R0402_1 | 22pF
37 | 1 | 1nF | C345 | C1206 | 1nF
38 | 1 | 10nF | C346 | c0402-nsk | 10nF
39 | 2 | 18pF | C348,C349 | c0402-nsk | 18pF
40 | 1 | 2.7PF | C530 | c0402-nsk | 2.7PF
41 | 1 | 10nF | C536 | C0603 | 10nF
42 | 1 | 100uF | C537 | CAP-SMD_BD6.3-L6.6-W6.6-RD | 100uF
43 | 1 | 10uF | C539 | C1206 | 10uF
44 | 1 | TF PUSH | CARD1 | TF-SMD_TF-PUSH
45 | 1 | PJ-313D | CN3 | AUDIO-SMD_PJ-313D-2
46 | 1 | BAT54C,215 | D1 | SOT-23-3_L2.9-W1.6-P1.90-LS2.8-BR
47 | 4 | ESD73034D | D2,D3,D29,D30 | DFN-10_L2.5-W1.0-P0.50-BL-2
48 | 2 | SS34 | D6,D32 | SMA_L4.3-W2.6-LS5.0-FD
49 | 2 | B5819WS-TP | D27,D28 | SOD-323_L1.8-W1.3-LS2.5-RD
50 | 1 | BSMD0805L-200 | F2 | F0805
51 | 1 | HC-FPC-03-09-31RLTAG | FPC1 | FPC-SMD_31P-P0.30_HC-FPC-03-09-31RLTAG
52 | 1 | FPC-05F-6PH20 | FPC2 | FPC-SMD_6P-P0.50_XUNPU_FPC-05F-6PH20
53 | 1 | AFC01-S24FCA-00 | FPC3 | FPC-SMD_24P-P0.50_AFC01-S24FCA-00
54 | 2 | HDR-M_2.54_1x3P | H1,H2 | HDR-TH_3P-P2.54-V-M
55 | 1 | HDR-M_2.54_1x2P | H5 | HDR-TH_2P-P2.54-V-M-1
56 | 1 | HDMI 19PIN 043 | HDMI1 | HDMI-SMD_HDMI-19PIN-043
57 | 5 | 470nH | L1,L2,L3,L4,L5 | IND-SMD_L2.0-W1.6_MHCHL201610A-1R0M-Q8A | 470nH
58 | 1 | BLM15AG121SN1D | L6 | L0402
59 | 6 | BLM18PG121SN1D | L7,L9,L11,L12,L23,L24 | L0603_1
60 | 2 | BLM18PG181SN1D | L8,L10 | L0603
61 | 1 | 240nH | L13 | IND-SMD_L2.5-W2.0_WPN252012H
62 | 1 | 15uH | L14 | IND-SMD_L7.3-W6.8 | 15uH
63 | 1 | 10uH | L16 | IND-SMD_L2.5-W2.0 | 10uH
64 | 1 | 3.3uH | L18 | IND-SMD_L4.4-W4.2 | 3.3uH
65 | 1 | HR911130C | L19 | RJ45-TH_HR911130C
66 | 1 | 2.2uH | L20 | IND-SMD_L2.5-W2.0_MHCHL2520 | 2.2uH
67 | 1 | GMI4015P-2C-42db | MIC1 | MIC-TH_BD4.0-P1.40-D0.4-L-FD
68 | 3 | LED_0402-R | PW,PW1,PW2 | LED_0402
69 | 4 | Key_SMD_4.2x3.2x2.5 | PWR,RST,RST1,RST2 | Key_SMD_4.2x3.2x2.5
70 | 1 | PUMH9,115 | Q1 | SOT-363_L2.0-W1.3-P0.65-LS2.1-BL
71 | 3 | AO3400A_N | Q2,Q3,Q4 | SOT-23-3_L2.9-W1.3-P1.90-LS2.4-BR
72 | 1 | CJ2301 S1 | Q5 | SOT-23-3_L3.0-W1.7-P0.95-LS2.9-BR
73 | 2 | MMBT5401 | Q6,Q7 | SOT-23-3_L2.9-W1.3-P1.90-LS2.4-BR
74 | 26 | 22 | R1,R13,R14,R15,R16,R17,R18,R20,R22,R27,R42,R64,R80,R81,R346,R347,R348,R349,R350,R351, R366,R367,R368,R369,R370,R371 | R0402 | 22
75 | 1 | 0Ω | R2 | r0402-nsk | 0Ω
76 | 1 | 1M | R3 | R0402 | 1M
77 | 6 | 0 | R5,R375,R376,R379,R380,R381 | R0402 | 0
78 | 8 | 100 | R6,R10,R40,R41,R47,R372,R377,R378 | R0402 | 100
79 | 1 | 120 | R7 | R0402 | 120
80 | 1 | 120Ω | R8 | r0402-nsk | 120Ω
81 | 10 | 2.2 | R9,R19,R21,R33,R34,R35,R36,R37,R325,R326 | R0402 | 2.2
82 | 1 | 200 | R12 | R0201 | 200
83 | 10 | 10K | R23,R67,R73,R74,R75,R171,R214,R216,R320,R336 | R0402 | 10K
84 | 8 | 4.7K | R24,R29,R352,R354,R356,R357,R358,R359 | R0402 | 4.7K
85 | 2 | DNP | R26,R28 | R0402 | 4.7K
86 | 1 | 1.62K | R32 | R0201 | 1.62K
87 | 5 | 0 | R38,R68,R323,R361,R362 | R0603 | 0
88 | 1 | 2.2k | R43 | R0402 | 2.2k
89 | 1 | 24kΩ | R44 | R0402 | 24kΩ
90 | 1 | 1kΩ | R45 | R0402 | 1kΩ
91 | 2 | 10kΩ | R46,R49 | R0402 | 10kΩ
92 | 2 | 51kΩ | R48,R66 | R0402 | 51kΩ
93 | 3 | 0402WGF1000TCE | R50,R51,R53 | R0402_1
94 | 3 | 0Ω | R52,R57,R61 | R0402_1 | 0Ω
95 | 2 | 47kΩ | R55,R166 | R0402_1 | 47kΩ
96 | 1 | 120kΩ | R56 | R0402_1 | 120kΩ
97 | 1 | 180kΩ | R59 | R0402_1 | 180kΩ
98 | 2 | 10kΩ | R60,R63 | R0402_1 | 10kΩ
99 | 1 | 56kΩ | R62 | R0402_1 | 56kΩ
100 | 1 | 100Ω | R65 | R0402 | 100Ω
101 | 5 | 2.2K | R69,R173,R174,R175,R176 | R0402 | 2.2K
102 | 1 | 0Ω | R70 | R0603_2 | 0Ω
103 | 2 | 240 | R71,R72 | r0402-nsk | 240
104 | 1 | 47K | R76 | R0402 | 47K
105 | 4 | 1K | R82,R83,R84,R219 | R0402 | 1K
106 | 1 | 3.24K | R85 | R0603 | 3.24K
107 | 1 | 30kΩ | R164 | R0402_1 | 30kΩ
108 | 1 | 33kΩ | R167 | R0402_1 | 33kΩ
109 | 1 | 150kΩ | R168 | R0402_2 | 150kΩ
110 | 2 | 2K | R169,R170 | R0402 | 2K
111 | 3 | 1.8K | R215,R217,R342 | R0402 | 1.8K
112 | 1 | 27K | R218 | R0402 | 27K
113 | 1 | 100K | R220 | R0402 | 100K
114 | 2 | 3.6R | R321,R322 | R0603 | 3.6R
115 | 1 | 100kΩ | R328 | R0402_1 | 100kΩ
116 | 1 | 4.7kΩ | R329 | R0402_1 | 4.7kΩ
117 | 1 | 20K | R337 | R0402 | 20K
118 | 2 | 510R | R343,R344 | R0402 | 510R
119 | 1 | 2.49K | R345 | R0402 | 2.49K
120 | 1 | 10K | R374 | R0603 | 10K
121 | 2 | 5.1K | R382,R383 | R0402 | 5.1K
122 | 1 | 6GHz | RF1 | IPEX-SMD_BWIPX-1-001E | 6GHz
123 | 1 | 24MHz | U1 | CRYSTAL-SMD_4P-L3.2-W2.5-BL | 24MHz
124 | 1 | TCS4525_WT | U2 | TCS4525
125 | 1 | EMMC04G-M627-A01 | U3 | fbga-153_l13.0-w11.5-p0.50_klmag1jetd-b041
126 | 1 | RK3568 | U4 | BGA-636_L19.0-W19.0-P0.65-BL
127 | 1 | RK809-5 | U5 | RK809-5
128 | 1 | LPDDR4 | U6 | LPDDR4_MrX
129 | 4 | ESD5451N | U8,U9,U10,U11 | X1-DFN1006-2_L1.0-W0.6-P0.65-BI
130 | 6 | ESD5311X | U12,U13,U73,U74,U77,U81 | DFN1006-2L-BI
131 | 13 | ESD5341N | U14,U18,U19,U52,U53,U54,U55,U56,U57,U80,U82,U83,U84 | DFN1006-2L-BI_1
132 | 1 | CH224K | U15 | ESSOP-10_L4.9-W3.9-P1.0-LS6.0-TL-EP
133 | 1 | BSMD1206-100-13.2V | U16 | F1206
134 | 2 | ZX-MX1.25-2PLT | U17,U20 | CONN-SMD_2P-P1.25-MX1.25-2P-LT
135 | 1 | SY8113BADC | U26 | TSOT-23-6_L2.9-W1.6-P0.95-LS2.8-BR
136 | 1 | TPS5430DDAR | U27 | ESOP-8_L4.9-W3.9-P1.27-LS6.0-TL-EP
137 | 1 | RTL8211F-CG | U50 | RTL8211F-CG
138 | 1 | X05C2015GZ | U58 | FPC-SMD_15P-P0.50_XKB_X05C2015GZ
139 | 1 | BL_M8800DU6_40L | U69 | BL_M8800DU6_40L
140 | 1 | SY6280AAC | U78 | SOT-23-5_L3.0-W1.7-P0.95-LS2.8-BL
141 | 1 | SY7201ABC | U79 | SOT-23-6_L2.9-W1.6-P0.95-LS2.8-BR
142 | 2 | USB_TYPE-C-16P | USB1,USB2 | USB_TYPE-C-16P
143 | 1 | USB-301WD-ARY | USB3 | USB-TH_XUNPU_USB-301WD-ARY
144 | 1 | 32.768kHz | X1 | CRYSTAL-SMD_L3.2-W1.5-1 | 32.768kHz
145 | 1 | 25MHz | X2 | CRYSTAL-SMD_4P-L3.2-W2.5-BL_1 | 25MHz

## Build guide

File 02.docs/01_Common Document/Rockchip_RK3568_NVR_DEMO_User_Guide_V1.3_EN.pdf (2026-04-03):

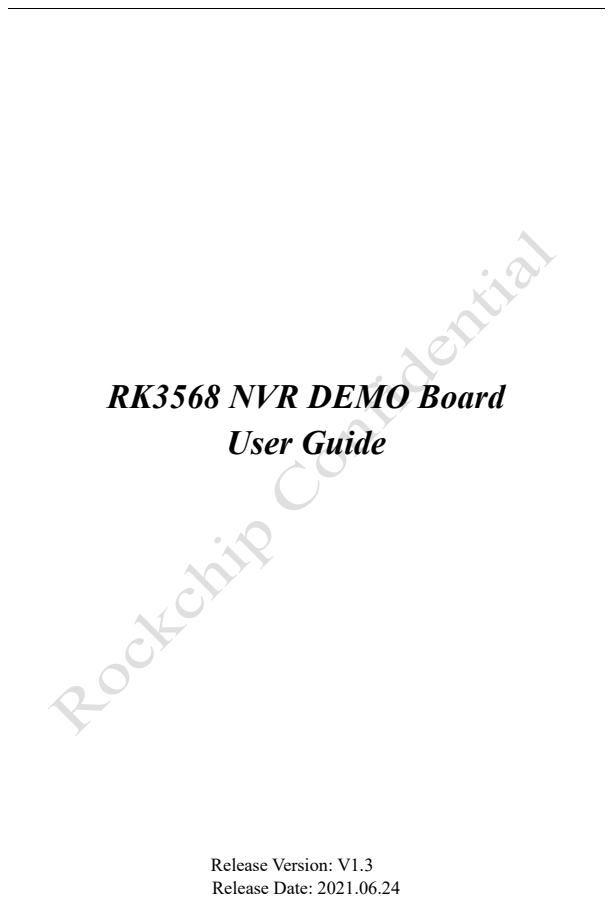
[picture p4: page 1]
User Guide; Release Version: V1.3 Release Date: 2021.06.24

RK3568 NVR DEMO Board

## Disclaimer

## Brand Statement

RK3568 DEMO Board User Guide

Copyright 2021 @ Rockchip Electronics Co., Ltd. | I

THIS DOCUMENT IS PROVIDED “AS IS”. ROCKCHIP ELECTRONICS CO., LTD. (“ROCKCHIP”)DOES NOT PROVIDE ANY WARRANTY OF ANY KIND, EXPRESSED, IMPLIED OR OTHERWISE, WITH RESPECT TO THE ACCURACY, RELIABILITY, COMPLETENESS,MERCHANTABILITY, FITNESS FOR ANY PARTICULAR PURPOSE OR NON-INFRINGEMENT OF ANY REPRESENTATION, INFORMATION AND CONTENT IN THIS DOCUMENT. THIS DOCUMENT IS FOR REFERENCE ONLY. THIS DOCUMENT MAY BE UPDATED OR CHANGED WITHOUT ANY NOTICE AT ANY TIME DUE TO THE UPGRADES OF THE PRODUCT OR ANY OTHER REASONS.

"Rockchip", "瑞芯微", "瑞芯" shall be Rockchip’s registered trademarks and owned by Rockchip. All the other trademarks or registered trademarks mentioned in this document shall be owned by their respective owners.

## Copyright © Rockchip Electronics Co., Ltd. 2021

Beyond the scope of fair use, neither any entity nor individual shall extract, copy, or distribute this document in any form in whole or in part without the written approval of Rockchip.

Rockchip Electronics Co., Ltd.
Address: No. 18 Building, A District, No.89,software Boulevard Fuzhou,Fujian,PRC Website: www.rock-chips.com
Customer service tel.: +86-4007-700-590
Customer service fax: +86-591-83951833
Customer service e-Mail: fae@rock-chips.com

## Preface

## Overview

RK3568 DEMO Board User Guide

Copyright 2021 @ Rockchip Electronics Co., Ltd. | II

This document is intended to introduce the basic functions and hardware characteristics, multi-function hardware configurations and software debug methods of RK3568 NVR DEMO board, aiming to help developers to get start with RK3568 NVR DEMO board and NVR solution more quickly and correctly.

## Product version

The product versions corresponding to this document are as follows:
Product name | Product version
RK3568 NVR DEMO | RK_NVR_DEMO_RK3568_DDR4P216SD4_V12_20201217

## Intended Audience

This document (this guide) is mainly intended for：
⚫ | Technical support engineers
⚫ | Single board hardware development engineers
⚫ | Embedded software development engineers
⚫ | Test engineers

## Revision History

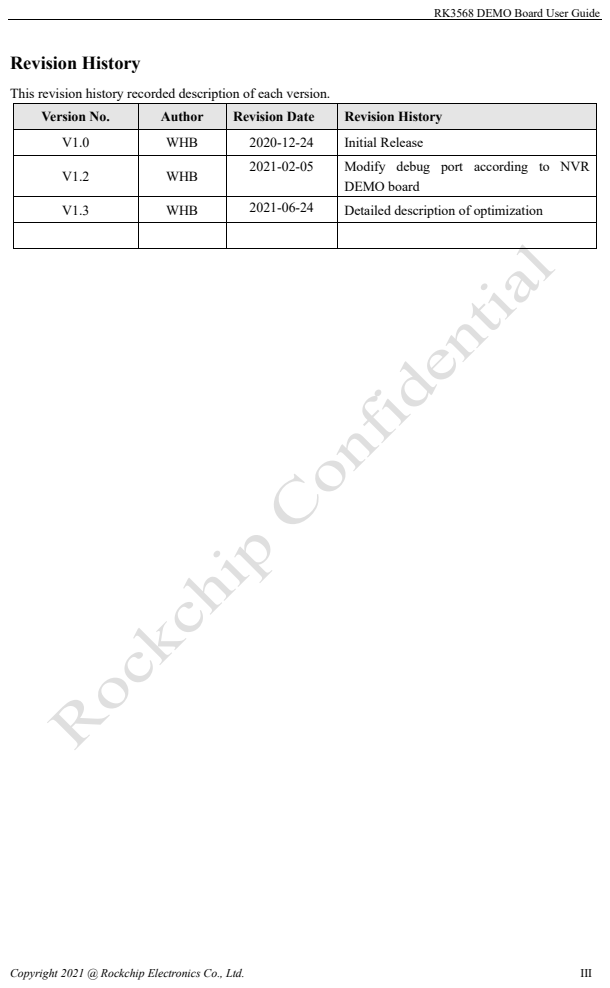
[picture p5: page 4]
Copyright 2021 @ Rockchip Electronics Co., Ltd.; III

RK3568 DEMO Board User Guide

This revision history recorded description of each version.

Version No. | Author | Revision Date | Revision History

V1.0 | WHB | 2020-12-24 | Initial Release
V1.2 | WHB | 2021-02-05 | Modify debug port according to NVR DEMO board

V1.3 | WHB | 2021-06-24 | Detailed description of optimization

RK3568 NVR DEMO Board User Guide

Copyright 2021 @ Rockchip Electronics Co., Ltd. | IV

## Acronyms

These Acronyms includes the abbreviations of commonly used phrases in this document.
Acronym | Description in English | Description in Chinese
CPU | Central Processing Unit | 中央处理器
NPU | Neural Network Processing Unit | 神经网络处理器
VPU | Video Processing Unit | 视频处理器
DDR | Double Data Rate | 双倍速率同步动态随机存储器
eMMC | Embedded Multi Media Card | 内嵌式多媒体存储卡
eDP | Embedded Display Port | 嵌入式数码音视讯传输接口
HDMI | High Definition Multimedia Interface | 高清晰度多媒体接口
I2C | Inter-Integrated Circuit | 内部整合电路(两线式串行通讯总线)
LDO | Low Drop Out Linear Regulator | 低压差线性稳压器
DCDC | Direct Current to Direct Current | 直流电转直流电
SARADC | Successive Approximation Register Analog to Digital Converter | 逐次逼近寄存器型模数转换器
UART | Universal Asynchronous Receiver/ Transmitter | 通用异步收发传输器
PWM | Pulse Width Modulation | 脉冲宽度调制
MIPI | Mobile Industry Processor Interface | 移动产业处理器接口
LVDS | Low-Voltage Differential Signaling | 低电压差分信号
PMIC | Power Management IC | 电源管理芯片
PMU | Power Management Unit | 电源管理单元
RK/Rockchip | Rockchip Electronics Co.,Ltd. | 瑞芯微电子股份有限公司
USB | Universal Serial Bus | 通用串行总线
SATA | Serial Advanced Technology Attachment | 串行高级技术附件
PCIe | Peripheral Component Interconnect Express | 外围组件快速互连
RGB | Red,Green,Blue；RGB color mode is a color standard in industry | 红绿蓝，RGB色彩模式, 是工业界的 一种颜色标准
VGA | Video Graphics Array | 电脑显示视频图像标准接口
ATX | Advanced Technology Extended | 高级技术扩展电源
ADB | Android Debug Bridge | 安卓调试桥
IR | Infrared Radiation | 红外线
RGMII | Reduced Gigabit Media Independent Interface | 精简吉比特介质独立接口

Copyright 2021 @ Rockchip Electronics Co., Ltd. | V

# Contents

Contents | V
Figures | VII
Tables | VIII

Copyright 2021 @ Rockchip Electronics Co., Ltd. | VI

Copyright 2021 @ Rockchip Electronics Co., Ltd. | VII

## Figures

Figure 3-6 The Location theTest Point When Using eMMC Entering Maskrom Flashing Mode ..17 Figure 3-7 The Location of SPI Nand and Test Point When Using SPI Nand Entering Maskrom.18

Copyright 2021 @ Rockchip Electronics Co., Ltd. | VIII

## Tables

Copyright 2021 @ Rockchip Electronics Co., Ltd. | 1

## 1 Overview

## 1.1 RK3568 Introduction

RK3568 is a quad-core ARM Cortex-A55 low-power and high-performance processor designed for personal mobile Internet devices and AIoT devices.
It provides many powerful embedded hardware engines to optimize the performance of advanced applications. The H.264 video decoder in RK3568 supports 4K@60fps, H.265 video decoder in RK3568 supports 4K@60fps, H.264/H.265 encoder supports 1080p@60fps, and high-quality JPEG codec. RK3568 embedded 3D GPU is fully compatible with OpenGL ES 1.1/2.0/3.2, OpenCL 2.0 and Vulkan 1.1; the special 2D hardware engine maximizes the display performance and can run smoothly at the same time. The built-in NPU supports INT8/INT16 mixed operation. Due to strong compatibility, network models based on a series of frameworks such as TensorFlow/MXNet/PyTorch/Caffe can be easily converted. There are high-performance external memory interfaces in RK3568 to ensure high-capacity and high-stability system operating memory bandwidth, and it supports multiple memory models such as DDR3, DDR3L, LPDDR3, DDR4, LPDDR4, LPDDR4X, etc.

## 1.2 RK3568 Block Diagram

Figure 1-1 RK3568 Block Diagram

## 1.3 System Introduction

### 1.3.1 System Diagram

RK3568 NRV DEMO board takes RK3568 as a core chip, uses discrete BUCK and LDO power chips for flexible layout. Uses DDR4, eMMC and SATA/PCIe and other functional external device interfaces for integrating a stable mass production solution. The detailed system block diagram is as follows:

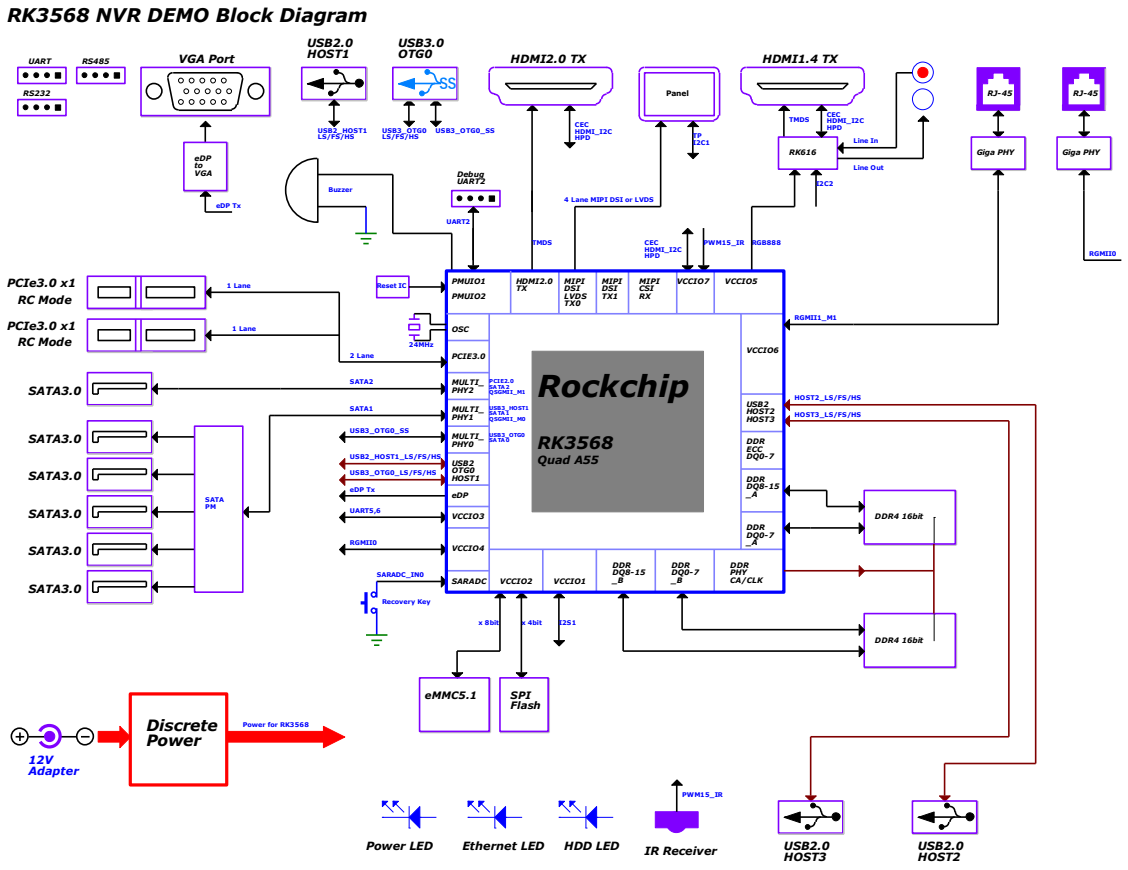
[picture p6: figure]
Panel; 4 Lane MIPI DSI or LVDS; PWM15_IR; RC Mode; MULTI_ PHY0; MULTI_ PHY1; x 4bit; SPI Flash; UART5,6; CEC HDMI_I2C HPD; RGB888; HDMI1.4 TX; TMDS; Line Out; Line In; Giga PHY; RGMII0; SARADC_IN0; eDP Tx; USB3_OTG0 LS/FS/HS; Discrete Power; USB3_OTG0_SS; Power for RK3568; SATA3.0; 2 Lane; PCIe3.0 x1; USB3.0 OTG0; USB3_OTG0_LS/FS/HS; USB2_HOST1_LS/FS/HS; SATA1; SATA2; SATA PM; 12V Adapter; Reset IC; eMMC5.1; UART; Debug UART2; UART2; 1 Lane; USB2.0 HOST1; USB2_HOST1 LS/FS/HS; DDR4 16bit; Power LED; Ethernet LED; HDD LED; IR Receiver; Recovery Key; Buzzer; x 8bit; HDMI2.0 TX; HOST3_LS/FS/HS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

Figure 1-2 RK3568 NVR DEMO System Diagram

### 1.3.2 Functions Overview

RK3568 NVR DEMO board includes the following functions:
- DC Power: ① DC 12V adapter power supply interface; ② One ATX main power interface; ③

one ATX + 12V DC interface;
- USB3.0 OTG: One USB3.0 interface which is used for system firmware upgrading;
- USB2.0 HOST1: One USB2.0 interface, which can be connected to mouse, U disk, USB HUB and other devices;
- USB 2.0 HOST2, HOST3: The standard 2.54mm 9pin interface which can be connected as 2 USB interfaces
- HDMI2.0 OUT: Support up to 4K@60Hz output;
- HDMI1.4 out: Convert RGB to HDMI output, supporting up to 1080p

- MIPI DSI/LVDS: Support 4lane MIPI or LVDS signal output, connected via FPC line;
- VGA OUT: Convert eDP signal to VGA output;
- Ethernet: Support 2 RGMII 10/100/1000M Ethernet;
- Audio Interface: Support audio output by a buzzer, line in and line out;
- SATA Interface: Support six 7pin SATA interfaces, one 4pin SATA power interface;
- Mini PCIe Interface: Two Mini PCIe, supports users to extend and debug PCIe devices;
- IR Receive: IR remote control input;
- LED Indicator Light: Working indicator, Ethernet connection indicator and hard disk connection indicator;
- System Key: Including Reset, Recover key and reserved MASKROM test point;
- UART debug: Debug and check log information;
- UART: Support external UART functional devices;
- RS232: Support external RS232 bus device;
- RS485: Support external RS485 bus device;

### 1.3.3 Functional Interfaces

Table 1-1 PCB Functional Interfaces Introduction

Functions | Useable or not
DDR4(512x16bit, total capacity is 2GB) | YES
eMMC (total capacity is 32GB) | YES
SPI Flash | It is NC by default SPI Flash or eMMC, just choose one
DC 12V Input (default power supply mode) | YES
ATX Power | YES
ATX Main POWER | Jumper resistances are needed, please refer to Section 3.1
USB3.0 OTG | YES
USB2.0 Host(3 Port) | YES
HDMI2.0 OUT | YES
RGB转HDMI1.4 OUT | YES
MIPI DSI/LVDS(4lane) | YES
VGA OUT | YES
RGMII 10M/100M/1000M (2 Port) | YES
Audio (beep、line in/out) | YES
SATA3.0 (6 Port) | YES
Mini PCIe Interface (2 Port) | YES
IR Receive | YES
UART Debug | YES
UART | YES
Indicator Light | YES
System Key | YES

Functions | Useable or not
RS232 | YES
RS485 | YES

### 1.3.4 Functional Modules Layout

The NVR DEMO board functional interfaces layout are showed as follows：

Figure 1-3 NVR DEMO Board Functional Interfaces Layout (TOP Surface)

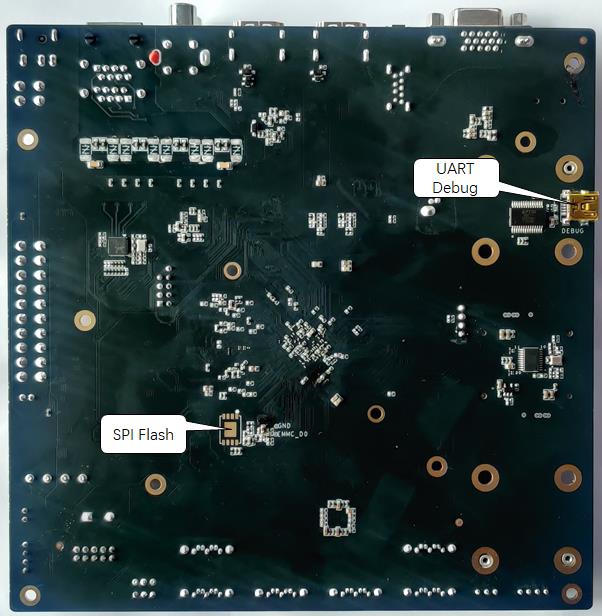
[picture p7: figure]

Figure 1-4 NVR DEMO Board Functional Interfaces Layout (Bottom Surface)

## 1.4 Components

RK3568 NVR DEMO board package includes the following components:
⚫ | One RK3568 NVR DEMO board
⚫ | One DC adapter: input 100V AC~240V AC, 50Hz, output DC12V DC, 3A

## 1.5 Power on and off

The way to power on and off the NRV DEMO board will be introduced as follows: ⚫ Power on by the following three ways of power supply
1. Powered by DC 12V power adapter (Default power supply mode).

2. Powered by ATX DC 12V power
3. Powered by ATX main power, but jumper resistances are required, please refer to Section 3.1 for details

⚫ The way to power off: Turn off the DC 12V adapter and the ATX Power supply to power off; if there is a hard disk, you need to power off through software, and then turn off the external power supply, otherwise the hard disk may be damaged.

## 1.6 Driver Upgrade

### 1.6.1 USB Driver Installation

It has to install the driver before upgrading the NVR DEMO board driver, the tool is located in: SDK\RKTools\windows\Release_DriverAssitant, open "DriverInstall.exe", click "Driver Installation", to install the driver. If a previous version driver has been installed, please click "Driver Uninstall" and reinstall the driver.
The driver file almost covers all current operating systems which can be supported.

Figure 1-5 Driver Installed Successfully

### 1.6.2 Driver Upgrade

There are two ways to upgrade the driver of RK3568 NVR DEMO board:
Enter Loader upgrade mode:
Ensure that SARADC_VIN0 is low before the system is powered on, press and hold RECOVER key of the board, the system will enter the Loader state.
Detailed steps are as follows:
1. Connect the USB3.0 OTG port to a PC, press and hold RECOVER key of the DEMO board.
2. The DEMO board is powered by 12V. If it has been powered on, press the reset key.
3. After the flashing tool shows that a Loader device is found, release the RECOVER key.
4. Select Loader, Parameter, Uboot, Recovery and other files on the flashing tool.
5. Click Execute to enter the upgrade state. The right side of the tool is the progress display bar, which displays the download progress and verification status.

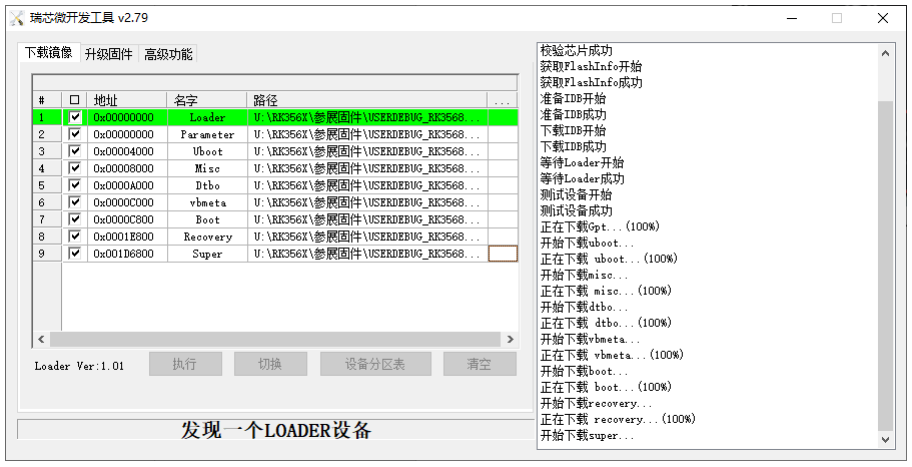
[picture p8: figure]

Figure 1-6 Loader Flashing Mode If you fail to upgrade in Loader mode, please enter Maskrom upgrade mode:
Before the system is powered on, connect eMMC_D0 to ground, causing eMMC to fail to boot and enter the Maskrom state.
Detailed steps are as follows:
1. Connect the USB3.0 OTG port to a PC, connect eMMC_D0 to GND by a tweezers
2. The DEMO board is powered by 12V. If it has been powered on, press the reset button.
3. After the flashing tool shows that a Maskrom device is found, release the connection of eMMC_D0 to GND. Note that in the Maskrom state, you need to select the corresponding Loader options to finish the upgrading.
4. Select Loader, Parameter, Uboot, Recovery and other files on the flashing tool.
5. Click Execute to enter the upgrade state. The right side of the tool is the progress display bar, which displays the download progress and verification status.

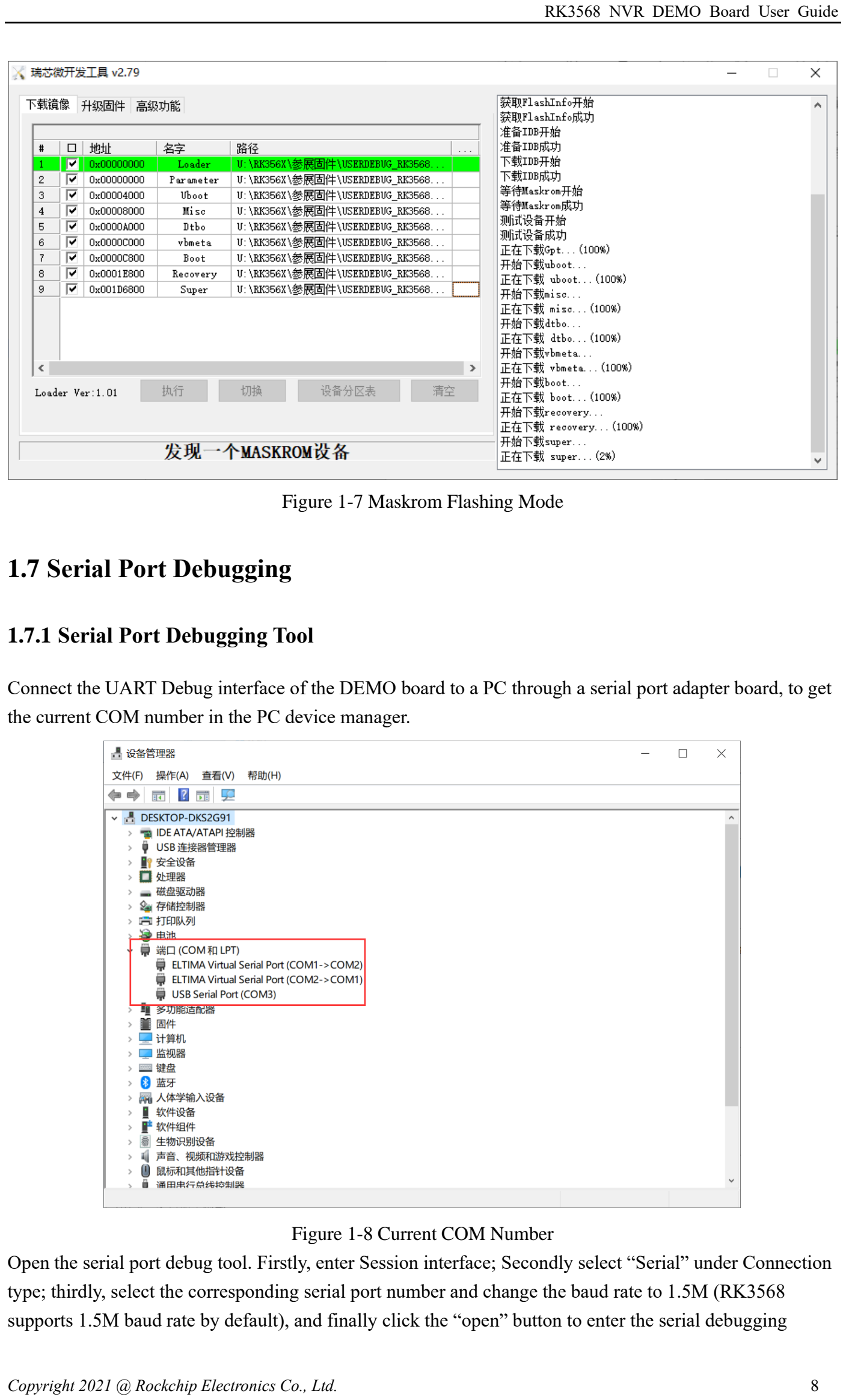
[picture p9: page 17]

Figure 1-7 Maskrom Flashing Mode

## 1.7 Serial Port Debugging

### 1.7.1 Serial Port Debugging Tool

Connect the UART Debug interface of the DEMO board to a PC through a serial port adapter board, to get the current COM number in the PC device manager.

Figure 1-8 Current COM Number Open the serial port debug tool. Firstly, enter Session interface; Secondly select “Serial” under Connection type; thirdly, select the corresponding serial port number and change the baud rate to 1.5M (RK3568 supports 1.5M baud rate by default), and finally click the “open” button to enter the serial debugging

interface.

Figure 1-9 Serial Port Tool Configuration Interface

Figure 1-10 Serial Port Tool Debugging Interface

### 1.7.2 ADB Debug

1. Ensure that the driver is installed successfully, and the PC is connected to the USB3.0 OTG port of the DEMO board;

2. Power on the DEMO board and boot into the system;
3. On the PC, Click start ---run ---cmd, enter the directory where the adb.exe tool is located, and input “adb devices” if the connected device is searched, indicating that the connection is successful;
4. Input "adb shell" to enter ADB debug.

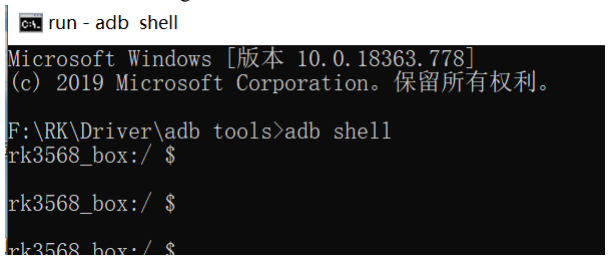
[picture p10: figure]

Figure 1-11 ADB Connected Successfully

## 2 Hardware Introduction

## 2.1 The Picture of NVR DEMO Board

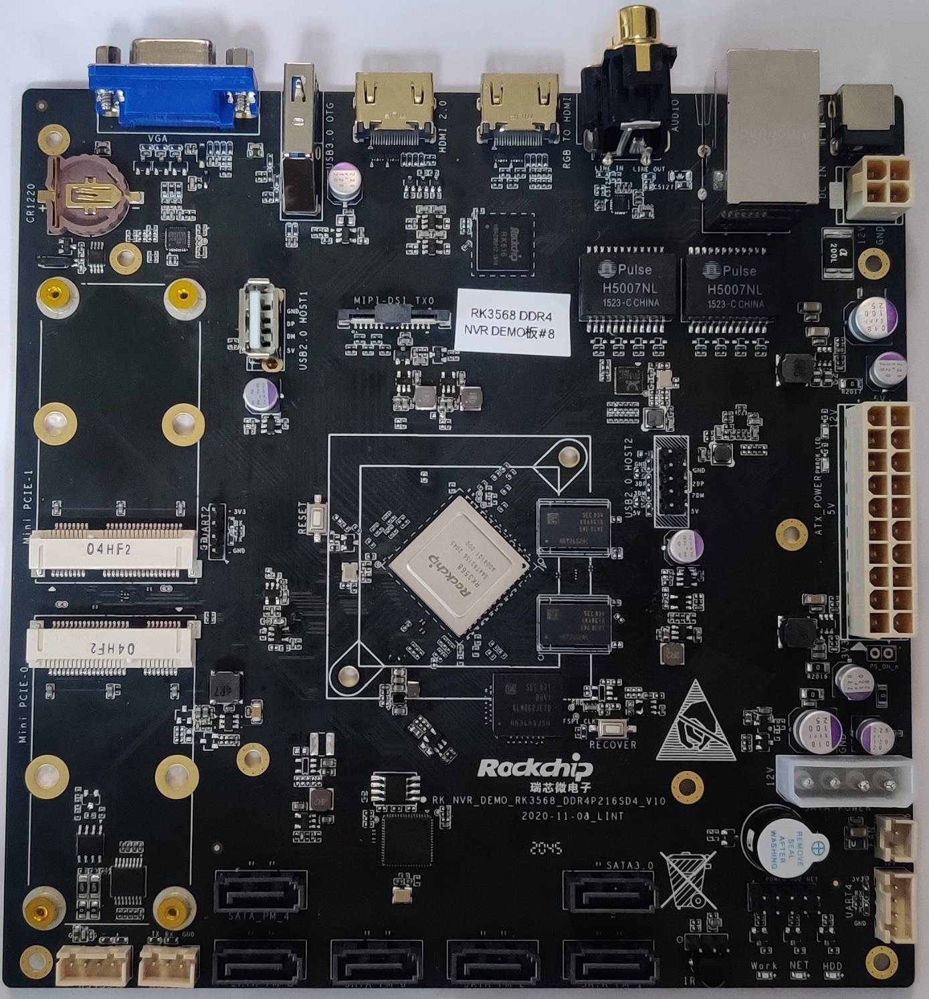
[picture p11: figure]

Figure 2-1 The Picture of NVR DEMO Board

## 2.2 Power Diagram

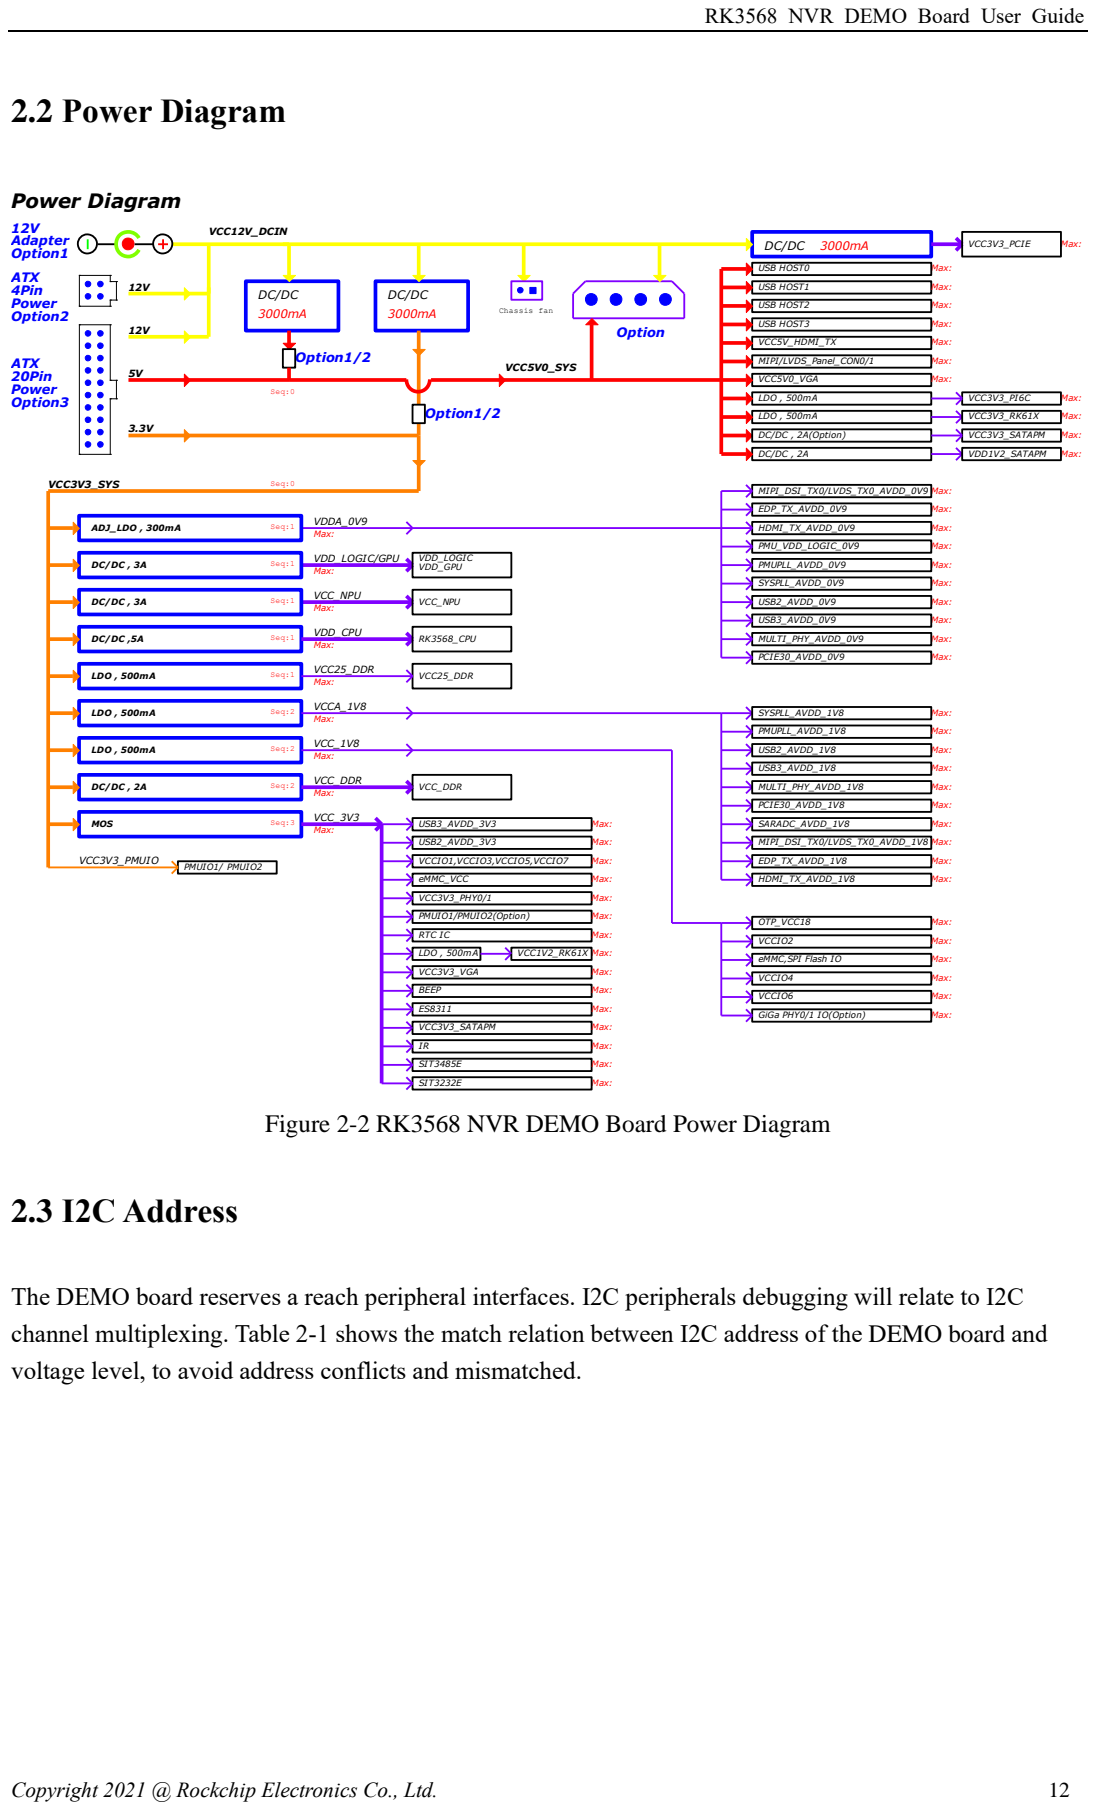
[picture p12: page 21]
2.3 I2C Address; Max:; Option; Option1/2; 12V Adapter Option1; VCC3V3_SYS; ATX 4Pin Power Option2; ATX 20Pin Power Option3; VCC12V_DCIN; VCC5V0_SYS; Chassis fan; VDDA_0V9 Seq:1; ADJ_LDO , 300mA; VDD_LOGIC/GPU Seq:1; Seq:1; VDD_LOGIC; VDD_GPU; VCC_NPU VCC_NPU; RK3568_CPU VDD_CPU; Seq:2; VCC_1V8 Seq:2; VCCA_1V8 LDO , 500mA; VCC_DDR VCC_DDR DC/DC , 2A; Seq:3; VCC_3V3; LDO , 500mA; MOS; VCC25_DDR VCC25_DDR LDO , 500mA; MULTI_PHY_AVDD_0V9; PMU_VDD_LOGIC_0V9; PMUPLL_AVDD_0V9; EDP_TX_AVDD_0V9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

DC/DC , 2A(Option)

eMMC,SPI Flash IO

GiGa PHY0/1 IO(Option)

Figure 2-2 RK3568 NVR DEMO Board Power Diagram

The DEMO board reserves a reach peripheral interfaces. I2C peripherals debugging will relate to I2C
channel multiplexing. Table 2-1 shows the match relation between I2C address of the DEMO board and
voltage level, to avoid address conflicts and mismatched.

Table 2-1 Match Relation Between I2C Address and IO Voltage Level
I2C Channel | Devices | I2C address | Power domain
I2C0 | TCS4525（DCDC） | 0X1C | 3.3V
I2C1 | HYM8563TS（RTC） | Read：0XA3 Write：0XA2 | 3.3V
I2C1 | MIPI CSI/LVDS | TBD | 3.3V
I2C1 | RTD2166(VGA) | | 3.3V
I2C3 | RK616(HDMI) | 0X50 | 3.3V
I2C3 | ES8311(Audio) | CE=0,0X18 CE=1,0X19 | 3.3V

Note: when using an extension board, please ensure that the I²C address of the extension board does not conflict with

the I²C address of the DEMO board

## 2.4 Extension Connectors

Users may use extension boards in practical use. There are several types of connectors for DEMO board: J5200 is a vertical double-row 30pins with 0.5mm pins and 1mm pitch (corresponding to the FPC cable with 0.5mm pitch, 30pin), the dimensions are as follows:

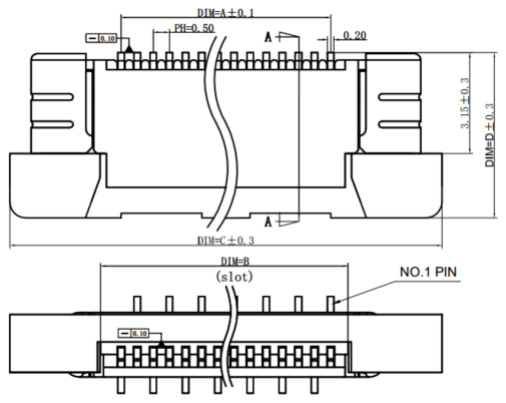
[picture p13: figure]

Figure 2-3 Vertical Double Row 30 PIN PCB Package with 1mm Pitch

## 2.5 Reference Materials

The reference diagram and PCB version information of the NVR DEMO board are as follows RK_NVR_DEMO_RK3568_DDR4P216SD4_V12_20201217.DSN RK_NVR_DEMO_RK3568_DDR4P216SD4_V12_20201218.brd

## 3 Modules Introduction

## 3.1 Power Input

The following are three ways of power input:
1. Only 1 external hard disk: powered by an adapter to input 12V/3A power; if you connect multiple hard disks, the adapter can also be used for power supply when the total power does not exceed the maximum power of the adapter.
2. 6 external hard disks: powered by ATX +12V DC Power (not provided by default)
3. 6 external hard disks: powered by ATX Main Power (not provided by default)
The power adapter and ATX +12V DC Power input 12V power, after going through the front-end step-down converter (buck) power, will get the system power VCC5V0_SYS and VCC3V3_SYS which will provide to multiple discrete DCDC and LDOs to output different voltages for system.
You have to disconnect the resistor R2016/R2017 when using ATX Main Power, and directly provide
VCC12V_DCIN, system power VCC5V0_SYS and VCC3V3_SYS, and then provide the system voltage to multiple discrete DCDCs and LDOs to output different voltages for system.
Power adapter input port and front-end Buck converter:

Figure 3-1 DC12V Input and Front-end Buck Converter One 20pin ATX Main POWER interface, which complies with Version1.0 standard; one 4pin ATX +12V DC interface.

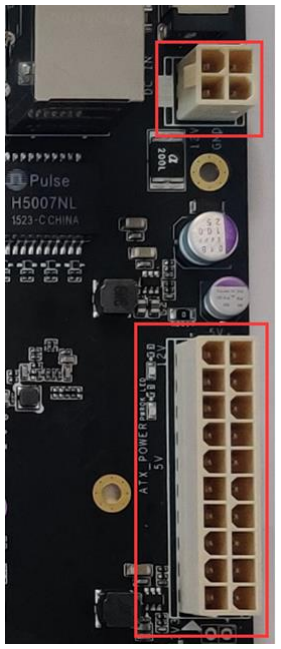
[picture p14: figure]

Figure 3-2 ATX Main POWER and ATX +12V DC Interface The 20pin ATX Main POWER interface signals are as follows:

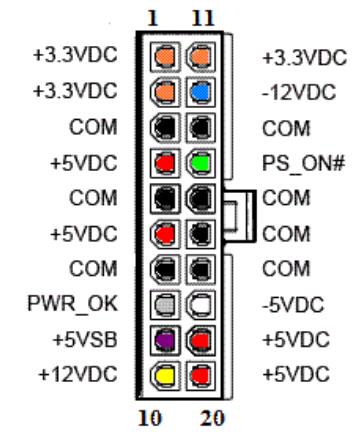
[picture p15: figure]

Figure 3-3 20pin ATX Main POWER Version1.0 Interface Signal

The 4pin ATX +12V DC interface signals are as follows:

Figure 3-4 4pin ATX +12V DC Interface Signal

## 3.2 Memory

1.eMMC
⚫ | The memory on the DEMO board is eMMC FLASH with the capacity of 32GB by default
⚫ | There is a Maskrom test point reserved on the DEMO board for entering Maskrom to upgrade firmware
2.SPI Flash
⚫ | The DEMO board reserves SPI Flash location and there is a Maskrom test point reserved on the DEMO board
| for entering Maskrom to upgrade firmware
2.DDR
⚫ The DDR on the DEMO board uses two 512M×16bit DDR4, with a total capacity of 2GB

Figure 3-5 DDR4 and eMMC
The test point location of NVR DEMO board for entering Maskrom flashing mode:

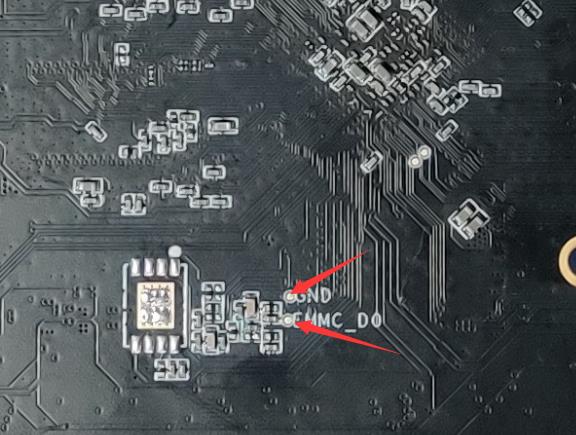
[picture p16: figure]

Figure 3-6 The Location theTest Point When Using eMMC Entering Maskrom Flashing Mode

Figure 3-7 The Location of SPI Nand and Test Point When Using SPI Nand Entering Maskrom

## 3.3 RTC Circuit

The RTC circuit is based on HYM8563TS chip, which can be powered by the DEMO Board or built-in button battery. It can keep providing accurate time even when the board is powered off, and communicate with the controller through I2C signal.

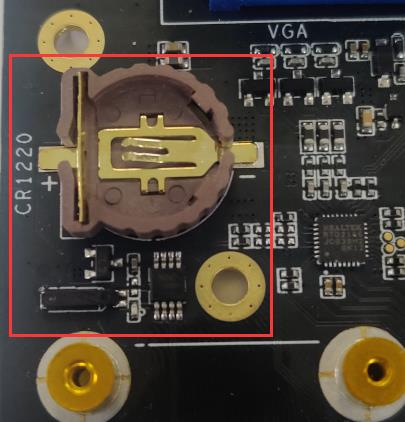
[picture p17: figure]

Figure 3-8 RTC Circuit

## 3.4 Keys Input

The DEMO board takes SARADC_VIN0 as RECOVER detection port, supports 10-bit resolution, and it will go to loader flashing mode by the RECOVER key; in addition, there is also a RESET key on the board, which is convenient for resetting and restarting the device through hardware; Keys location are as follows:

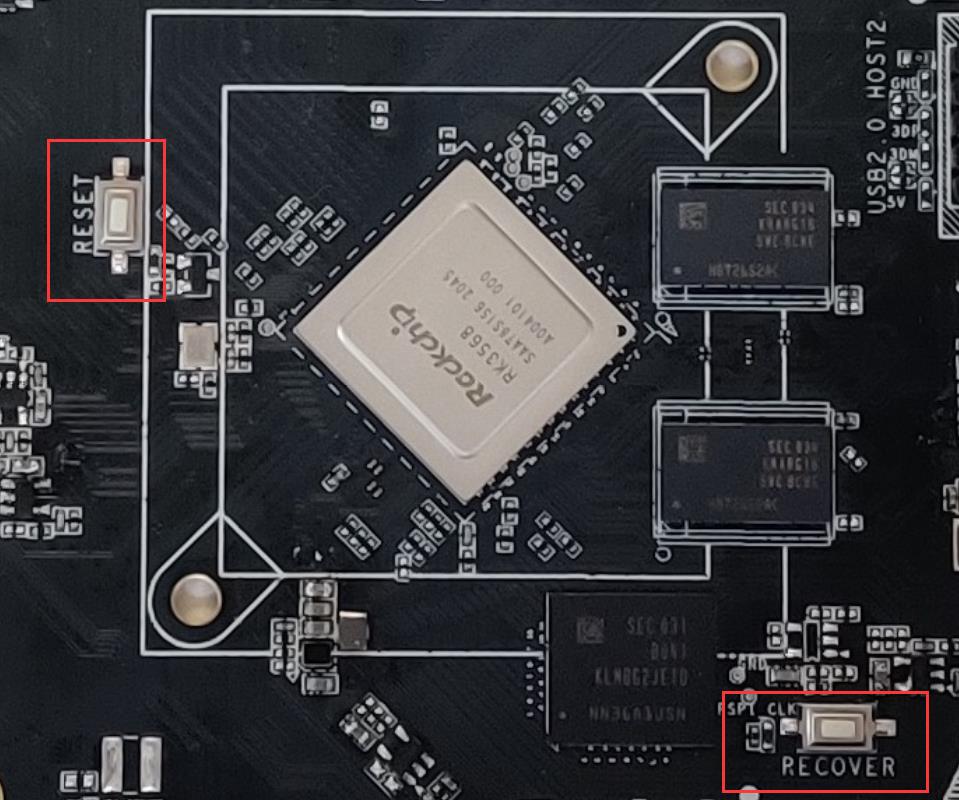
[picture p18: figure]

Figure 3-9 Keys Location

## 3.5 Infrared Receiver

The small infrared receiver on the DEMO board is general model IRM3638, with a center frequency of 38KHz.

Figure 3-10 IR Receiver

## 3.6 UART Interface

The DEMO board reserves UART interfaces, which communicate with the controller through UART4. The external standard 4 PINS 2.54mm male socket is convenient for UART peripheral debugging.

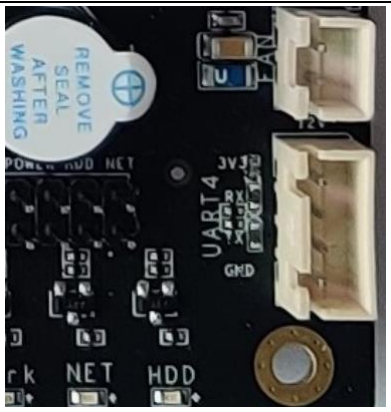
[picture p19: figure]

Figure 3-11 UART Interface

## 3.7 UART Debug Interface

The DEMO board provides a serial port for debugging, it is UART2 by default, use FT232RL chip to covert UART signal to USB signal, providing a mini USB interface to connect with PC and the baud rate is 1.5M by default.

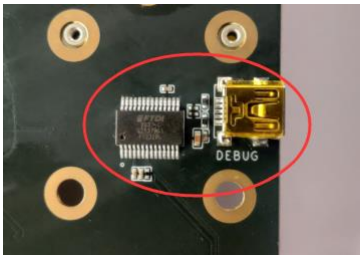
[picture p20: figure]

Figure 3-12 UART Debug Interface

## 3.8 RS485 and RS232 Interface

The RS485 bus on the DEMO board is based on SIT3485E chip, and communicates with the controller through UART6 serial port, providing an external standard 4 PINS 2.54mm male socket for debugging; RS232 bus is based on SIT3232E chip and communicates with the controller through UART5 serial port, provides an external standard 3 PINS 2.54mm male socket for debugging.

Figure 3-13 RS485 and RS232 Interface

## 3.9 MIPI/LVDS Output Interface

The MIPI/LVDS output interface uses a vertical connector with a pitch of 1mm.

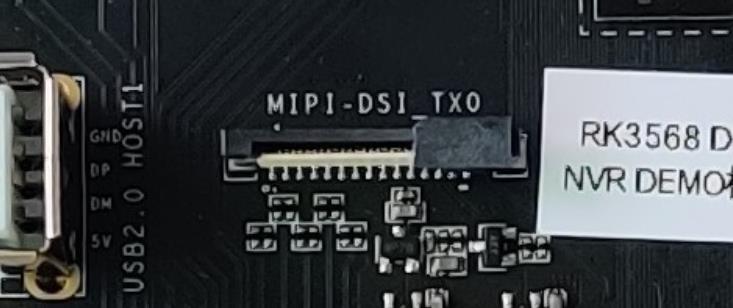
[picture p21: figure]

Figure 3-14 Video Output Interface

The MIPI_TX interface signal sequence is as follows: Table 3-1 The MIPI_TX Signal Definition
1 | GND
2 | | MIPI_DSI_TX0_D0N
3 | MIPI_DSI_TX0_D0P
4 | | GND
5 | MIPI_DSI_TX0_D1N
6 | | MIPI_DSI_TX0_D1P
7 | GND
8 | | MIPI_DSI_TX0_CLKN
9 | MIPI_DSI_TX0_CLKP
10 | | GND
11 | MIPI_DSI_TX0_D2N
12 | | MIPI_DSI_TX0_D2P
13 | GND
14 | | MIPI_DSI_TX0_D3N

15 | MIPI_DSI_TX0_D3P
16 | | GND
17 | LCD0_BL_PWM14_M0
18 | | NC
19 | VCC3V3_LCD0
20 | | NC
21 | NC
22 | | LCD0_PWREN_H
23 | I2C_SCL_TP0
24 | | ISC_SDA_TP0
25 | TP_INT_L
26 | | TP_RST_L
27 | GND
28 | | VCC5V0_SYS
29 | VCC5V0_SYS
30 | | VCC5V0_SYS

## 3.10 HDMI Output Interface

The DEMO board supports HDMI output, the left interface outputs HDMI signals by controller directly, supporting HDMI2.0 protocol, the right interface uses RK616 chip to convert RGB to HDMI signal, supporting HDMI1.4 protocol, and the output connectors are HDMI A interfaces.

Figure 3-15 HDMI Output Interface

## 3.11 VGA Output Interface

The DEMO board converts eDP to VGA signal through RTD2166 chip, and the external standard VGA socket is convenient to connect with VGA monitor.

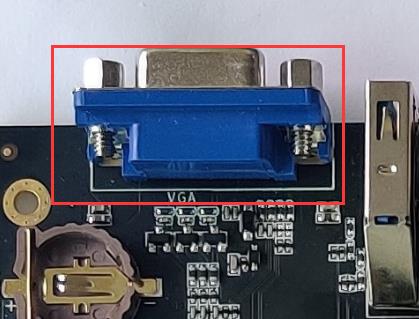
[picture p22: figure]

Figure 3-16 VGA Output Interface

## 3.12 Audio Input and Output Interface

The DEMO board convert RK3568 I2S to Line in/out signal by ES8311 chip by default, or output Line in/out signal by RK616; control the buzzer to output audio by another GPIO port.

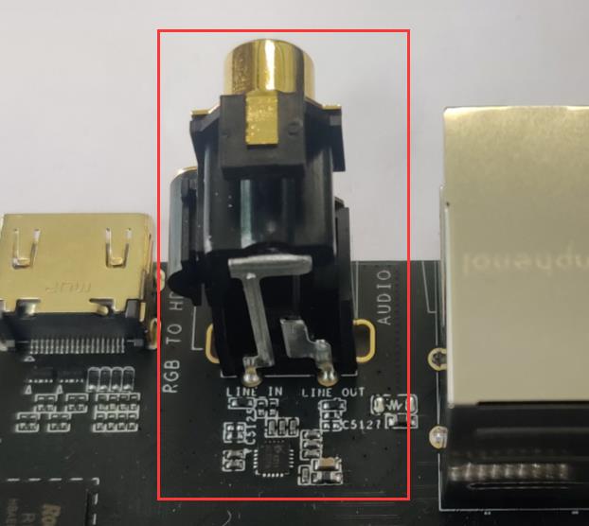
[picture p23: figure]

Figure 3-17 Audio Line in/out Interface

Figure 3-18 Buzzer

## 3.13 USB OTG/HOST Interface

The DEMO board with USB OTG and USB HOST interface:
USB3.0 OTG consists of 2 USB3.0 high-speed signal lines and one OTG signal line, and is connected to USB3.0 standard-A interface, and is backward compatible with USB 2.0 specifications. Therefore, this interface can be used to download and upgrade firmware, or as a USB3.0 HOST.
USB2.0 HOST1 uses USB2.0 Standard-A interface and standard 4 PIN 2.54mm male dual layout. You can directly use the standard USB2.0 A port to communicate with peripherals, or transfer the 4pin to standard USB2.0 A through an adapter cable.

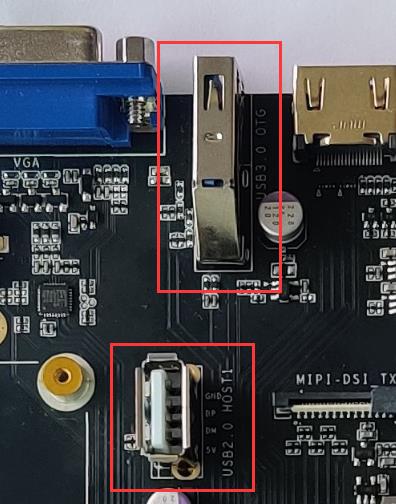
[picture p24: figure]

Figure 3-19 USB3.0 OTG and USB3.0 HOST1 Interface

USB2.0 HOST2/3 is a standard 9 PIN 2.54mm male socket, which can be convert to 2 standard USB2.0 A ports by an adapter cable, and convenient for extension.

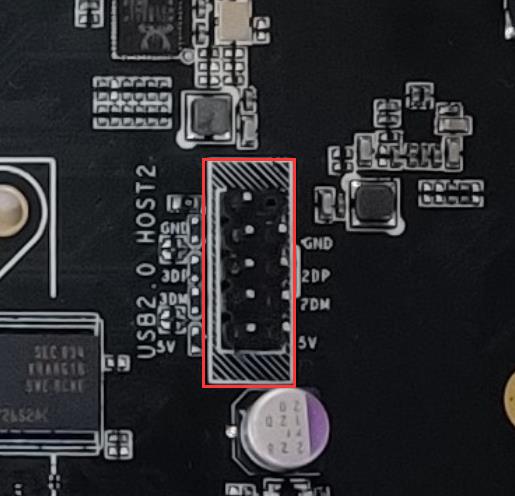
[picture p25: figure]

Figure 3-20 USB2.0 HOST2/3 Interface

## 3.14 Ethernet Interface

The DEMO board supports two RJ45 interfaces and provide dual Gigabit Ethernet connections. Both channels use the Gigabit Ethernet MAC integrated inside RK3568 and are connected to an external PHY chip with the model of RTL8211F-CG, and the features are as follows:
⚫ | Compatible with IEEE802.3 standard, support full-duplex and half-duplex operation, support cross detection
| and self-adaptation.
⚫ | Support 10/100/1000M data rate.
⚫ | The interface takes dual RJ45 interface units without isolation transformer.

Figure 3-21 RJ45 Interface

## 3.15 Mini PCIe Interface

The DEMO board uses two standard Mini PCIe3.0 connectors which is compliant with standard PCI Express Mini Card version 1.2 protocol, you can install external PCIe board for communication, for example, external Toybrick TB-RK1808M0 Mini-PCIe computing card to enhance computing capability.
⚫ | Working mode: Root Complex (RC).
⚫ | Supports 1 lane data interface.
⚫ | The 100MHz clock is provided by an external clock chip.

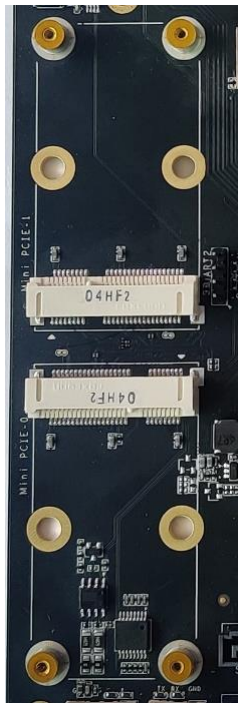
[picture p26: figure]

Figure 3-22 Mini PCIe3.0 Connector

## 3.16 SATA Interface

The DEMO board supports six SATA3.0 interfaces, in which, SATA1_TXP/TXN is directly output by controller, and the other SATA2_TXP/TXN is converted to 5 SATA interfaces output through SATA HUB chip JMB575

Figure 3-23 SATA Interface

## 3.17 Indicator Lights

There are three power indicator lights on the DEMO board, they are the working status indicator light, the Ethernet working indicator light, and the hard disk working indicator light from left to right respectively.

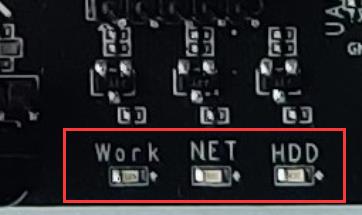
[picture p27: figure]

Figure 3-24 Indicator Lights

RK3568 DEMO Board User Guide

## 4 Notice

## 4.1 Notice

RK3568 DEMO board is suitable for lab or project environment. Please read the following notices before operation:
- Before unpacking and installing the DEMO board, please take the necessary anti-static measures to avoid the damage to the hardware of the DEMO board caused by ESD;
- Please hold the edge of the DEMO board, and do not touch the exposed metal part of the DEMO board so as to avoid the electrostatic damage to the components of the DEMO board;
- Please place the DEMO board on a dry plane to keep them away from heat source, electromagnetic interference source and radiation source, electromagnetic radiation sensitive equipment (such as medical equipment) and so on.

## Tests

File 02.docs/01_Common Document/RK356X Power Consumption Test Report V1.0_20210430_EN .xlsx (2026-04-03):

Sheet: Title Page
RK356X
Power Consumption Test Report
Revision: V1.0
Date: 2020/04/30
Status: Official Release
Rockchip Confidential

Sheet: Statement
IMPORTANT NOTICE: This document is from Rockchip Electronics Co., Ltd. .The contents of this document and any attachments may contain information that is privileged, confidential and/or exempt from disclosure under applicable law and relevant NDA. If you are not the intended recipient, you are hereby notified that any disclosure, copying, distribution, or use of the information is STRICTLY PROHIBITED. Please immediately contact the sender as soon as possible and destroy the material in its entirety in any format. Thank you.

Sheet: Change history
Revision History
Revision Record
Revision | Description | Editor | Release Date
V1.0 | First edition | Wayne | 20210430
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

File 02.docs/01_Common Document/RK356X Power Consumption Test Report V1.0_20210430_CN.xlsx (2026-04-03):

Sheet: 封面
RK356X
Power Consumption Test Report
Revision: V1.0
Date: 2020/04/30
Status: Official Release
Rockchip Confidential

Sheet: 申明
保密提示： 本文档及其附件可能含有机密信息，来自瑞芯微电子股份有限公司，仅发送给指定接收者。若非该特定接收人，请勿复制、 使用或披露本文档的任何内容。若误收本文档，请从系统中永久性删除本文档，并以回复邮件或其他方式即刻告知发件人。瑞芯微电子股份有限公司拥有本文档信息的著作权及解释权，禁止任何未经授权许可的侵权行为。 IMPORTANT NOTICE: This document is from Rockchip Electronics Co., Ltd. .The contents of this document and any attachments may contain information that is privileged, confidential and/or exempt from disclosure under applicable law and relevant NDA. If you are not the intended recipient, you are hereby notified that any disclosure, copying, distribution, or use of the information is STRICTLY PROHIBITED. Please immediately contact the sender as soon as possible and destroy the material in its entirety in any format. Thank you.

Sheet: 更改记录
Revision History
Revision Record
Revision | Description | Editor | Release Date
V1.0 | First edition | Wayne | 20210430
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
